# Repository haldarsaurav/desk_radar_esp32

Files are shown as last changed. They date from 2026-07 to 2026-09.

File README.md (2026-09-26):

# MUC Desk Radar

**Munich · Revision 2.1 base + unnumbered screen-look update · 26 September 2026**

Designed and built by **Saurav Haldar**.

> Copyright 2026 Saurav Haldar / @haldarsaurav. All rights reserved. Permission is required
> for reuse. See the [licence](LICENSE) and [permission guide](docs/PERMISSIONS.md).

<p align="center">
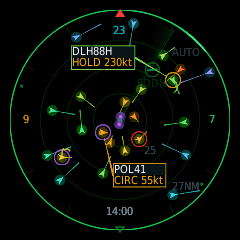
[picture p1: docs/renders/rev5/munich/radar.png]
MUC Desk Radar firmware render with example aircraft near Munich
  
</p>

<p align="center">
  <strong>A tiny, physical window into the sky above Munich.</strong>
</p>

MUC Desk Radar is a standalone Wi-Fi aircraft tracker built around an ESP32-S3 and a 240 × 240 round display. It turns live ADS-B positions, airport weather, orbital data and its own learned traffic history into a quiet desk instrument.

There is no phone app, subscription, account or home server. Once Wi-Fi is configured, the device talks directly to public data sources and draws everything locally.

**Real device photos:** reserved for Saurav's photos of the assembled radar in use. The images below are labeled firmware captures, setup-page captures or CAD renders; none is presented as a photograph of the finished device.

It answers the simple question that started the project—**“What is that plane?”**—but it also answers more interesting ones:

- Is that aircraft arriving, departing, holding, circling, surveying or going around?
- What will pass closest to home if every aircraft keeps its present course?
- Which contact is the most unusual—not merely the nearest?
- Is the sky genuinely busier than it normally is on this weekday and hour?
- Which runway direction is probably active?
- Where is the ISS in my sky, and when is its next useful pass?

> This repository is the public, presentation-only home of the project: the complete README guide, firmware renders, wiring information and enclosure concepts. It intentionally contains **no firmware source and no private configuration**.

---

## Revision history

| Revision | Date | Changes |
| --- | --- | --- |
| **Unnumbered look update** | 26 September 2026 | Original plus five selectable screen looks; portal picker, saved selection and 30 firmware render checks. |
| **2.1** | 26 September 2026 | Fixed airport sets; startup, settings, network, stale-data and portal audit fixes; expanded regression coverage; full project credit and measured running cost. |
| **2.0** | 25 September 2026 | Baseline snapshot, previously labelled product 2.3 / firmware 5.7.1. |

The owner has reset release numbering to **2.0 → 2.1**. Historical rev5.x and rev2.2/2.3
comments describe earlier development; current firmware, screen and boot labels are 2.1.

## Money to run

Measured running power: **0.6 W**. At that constant draw, leaving the radar on 24/7 uses
**0.0144 kWh/day**, **0.432 kWh per 30 days**, or **5.256 kWh per 365-day year**.

For a Freising example, [Freisinger Stadtwerke's MaxiStrom tariff](https://www.freisinger-stadtwerke.de/de/Energie-Wasser/Strom/Unsere-Tarife/) lists a gross energy price of **€0.3095/kWh** from 1 January 2026. At that rate, the radar adds about **€0.0045/day**, **€0.13 per 30 days**, or **€1.63/year** in electricity. This is the incremental energy charge on an existing connection; it excludes the tariff's standing charge. Your actual bill depends on your tariff and measured power over time.

## At a glance

| Item | Detail |
|---|---|
| Display | 1.28-inch GC9A01 round IPS, 240 × 240 pixels |
| Controller | ESP32-S3-WROOM-1 N16R8, dual core, 16 MB flash, 8 MB PSRAM |
| Local controls | One MODE button; all configuration is through a captive web page |
| Main aircraft refresh | Approximately every 8 seconds |
| Drawing rate | Approximately 40 frames per second |
| Stored contacts | Up to the nearest 96 contacts from the shared aircraft request |
| Radar AUTO ladder | 10, 15, 20, 30, 50, 75, 100, 150 or 250 km |
| Behavior memory | Up to 64 aircraft tracks × 48 position fixes |
| Traffic memory | 60 one-minute samples, an hourly baseline and a learned 7 × 24-hour weekly model |
| Special alerts | Squawk 7500, 7600 and 7700 |

---

## Real screens from the firmware

These are host-rendered examples from the firmware drawing code, not photographs or live captures. The screen set was regenerated from revision 2.1 using synthetic aircraft and weather fixtures; exact labels and units depend on settings. The descriptions below explain the current Munich configuration.

| Live radar | Munich Airport | Traffic now |
|---|---|---|
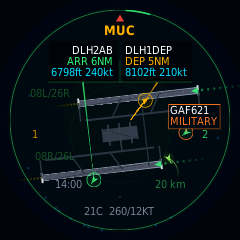
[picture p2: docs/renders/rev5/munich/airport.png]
Munich airport page
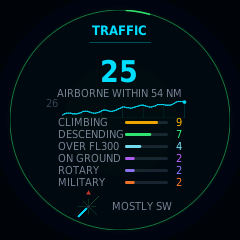
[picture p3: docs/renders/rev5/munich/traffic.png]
Munich traffic page
| Munich radar page |  |  |
| Nearest aircraft | Coolest aircraft | Space |
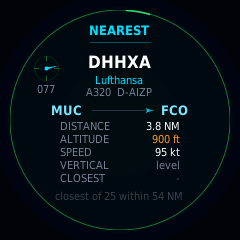
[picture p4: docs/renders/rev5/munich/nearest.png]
Nearest aircraft page
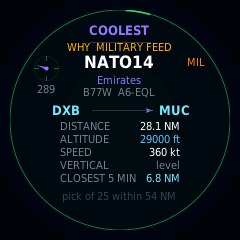
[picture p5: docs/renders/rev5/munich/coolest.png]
Coolest aircraft page
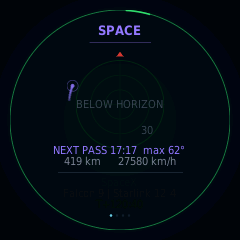
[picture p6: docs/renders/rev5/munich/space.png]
ISS and launches page
|  |  |  |
| Weather | Detected patterns | Learned trends |
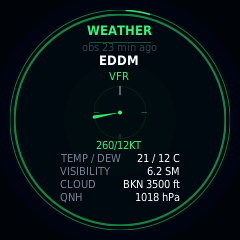
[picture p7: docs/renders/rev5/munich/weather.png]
Weather page
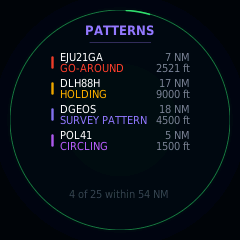
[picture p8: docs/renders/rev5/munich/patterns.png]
Flight patterns page
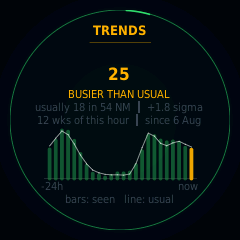
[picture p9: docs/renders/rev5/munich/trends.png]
Traffic trends page
|  |  |  |
| System health | About | Connection recovery |
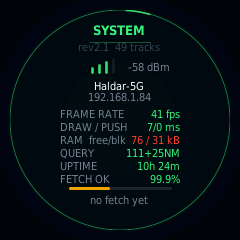
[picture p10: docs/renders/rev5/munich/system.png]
System page
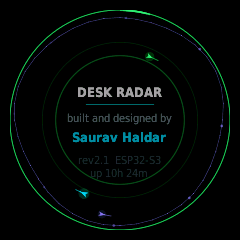
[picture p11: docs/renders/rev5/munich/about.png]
About page
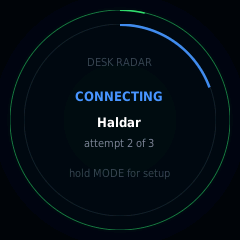
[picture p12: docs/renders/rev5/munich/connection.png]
Connection recovery page
|  |  |  |

---

## Six selectable screen looks

The current [firmware source](https://github.com/haldarsaurav/desk_radar_esp32_code) includes **Original plus five new looks**. Choose one under **Screen → Look** in the setup portal, then Save; the choice is stored and takes effect after the restart. Each look restyles the pages, connection and setup screens using the same aircraft and weather data. The images below come from the firmware's host renderer with synthetic data; they are not device photographs. Each linked strip covers the normal pages and special states.

| Look | Firmware render | More render checks |
|---|---|---|
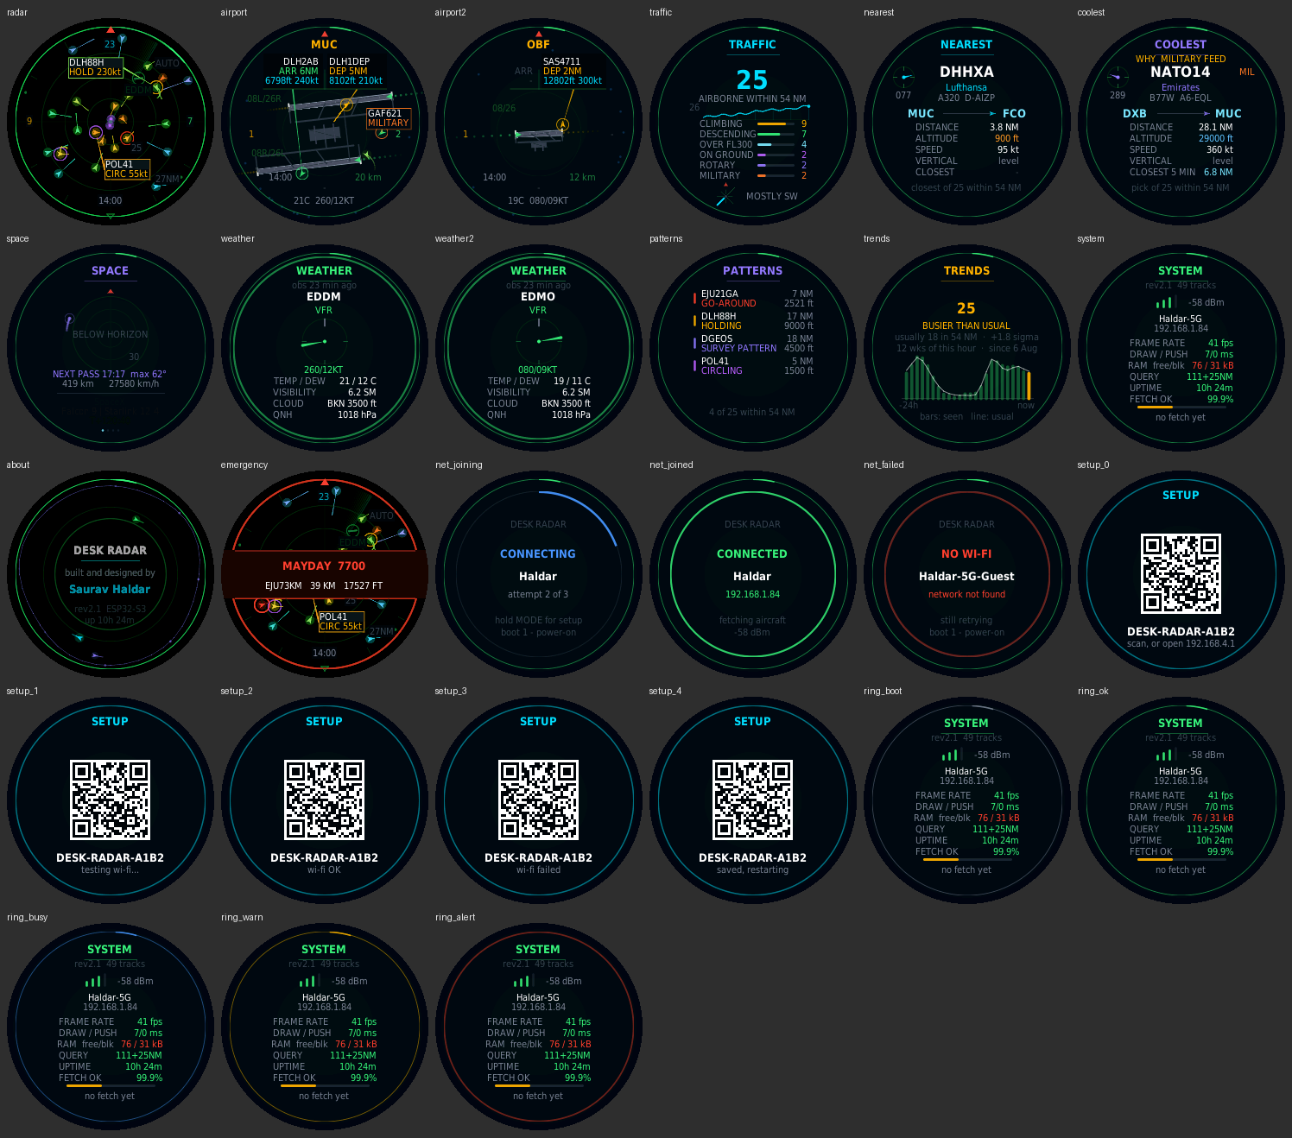
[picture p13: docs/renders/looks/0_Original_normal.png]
Original look across Desk Radar pages
| Original |  | [Empty](docs/renders/looks/0_Original_empty.png) · [Stale](docs/renders/looks/0_Original_stale.png) · [Stress](docs/renders/looks/0_Original_stress.png) · [Metric](docs/renders/looks/0_Original_metric.png) |
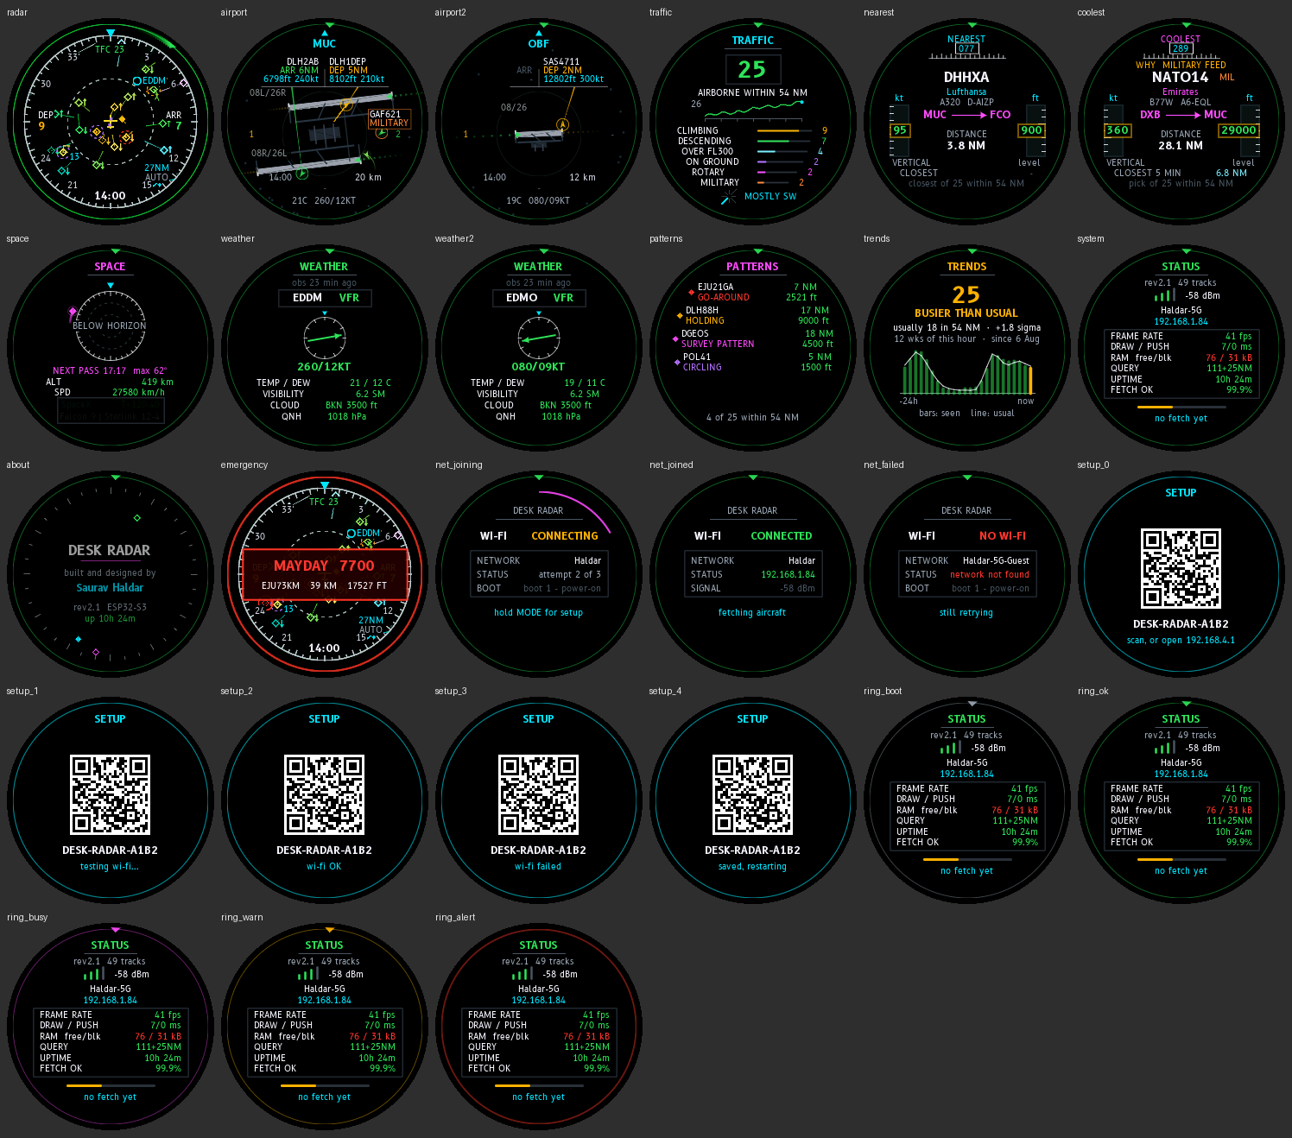
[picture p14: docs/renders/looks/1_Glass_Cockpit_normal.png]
Glass Cockpit look across Desk Radar pages
| Glass Cockpit |  | [Empty](docs/renders/looks/1_Glass_Cockpit_empty.png) · [Stale](docs/renders/looks/1_Glass_Cockpit_stale.png) · [Stress](docs/renders/looks/1_Glass_Cockpit_stress.png) · [Metric](docs/renders/looks/1_Glass_Cockpit_metric.png) |
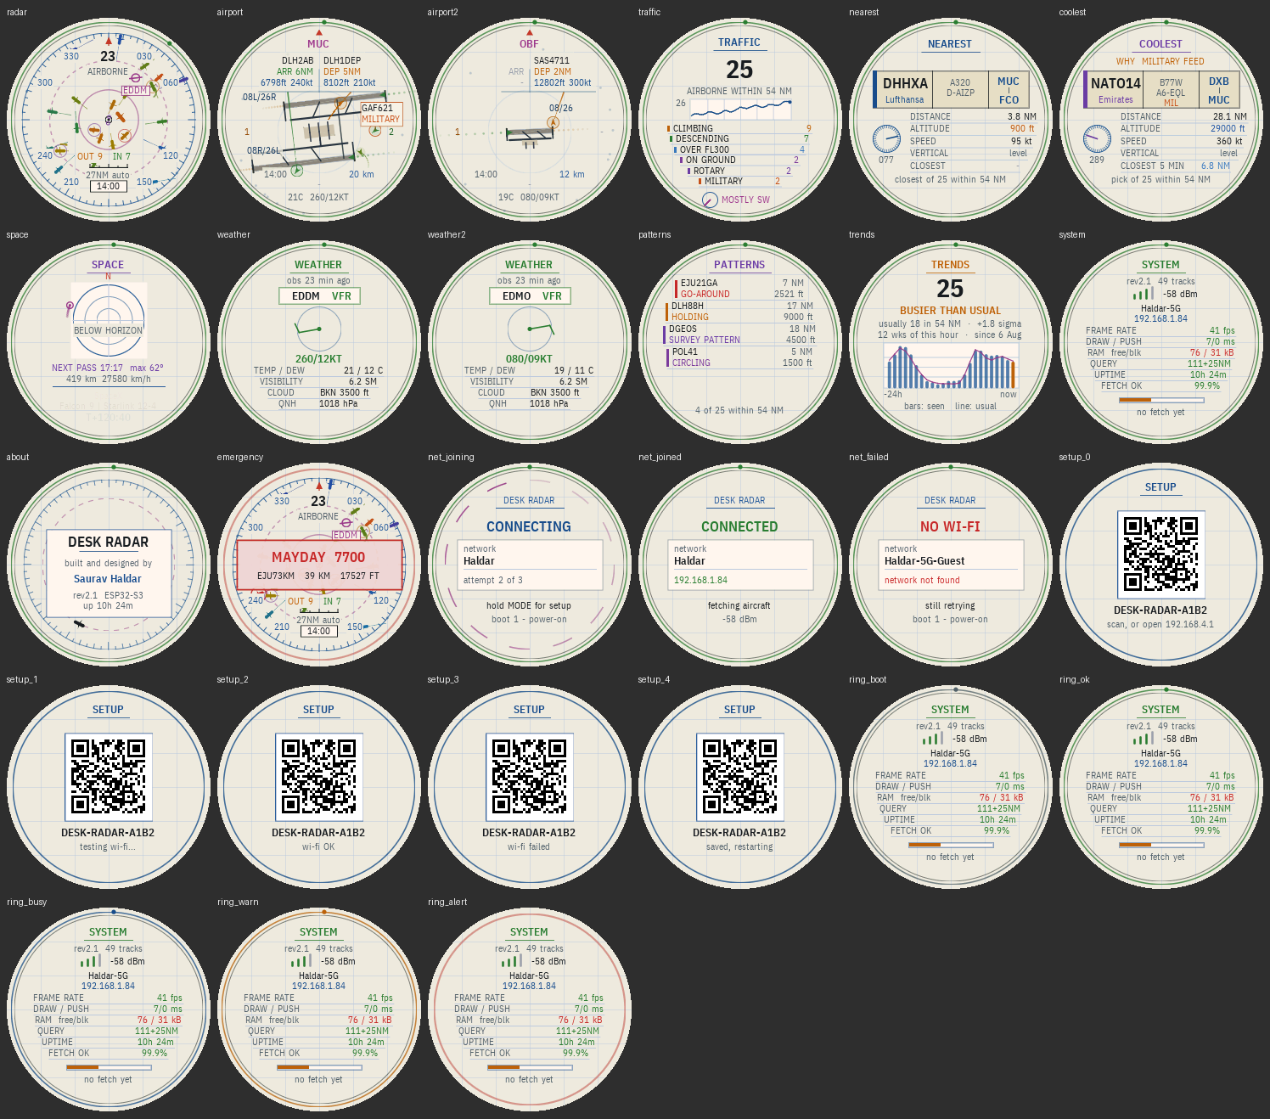
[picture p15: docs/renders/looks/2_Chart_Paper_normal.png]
Chart Paper look across Desk Radar pages
| Chart Paper |  | [Empty](docs/renders/looks/2_Chart_Paper_empty.png) · [Stale](docs/renders/looks/2_Chart_Paper_stale.png) · [Stress](docs/renders/looks/2_Chart_Paper_stress.png) · [Metric](docs/renders/looks/2_Chart_Paper_metric.png) |
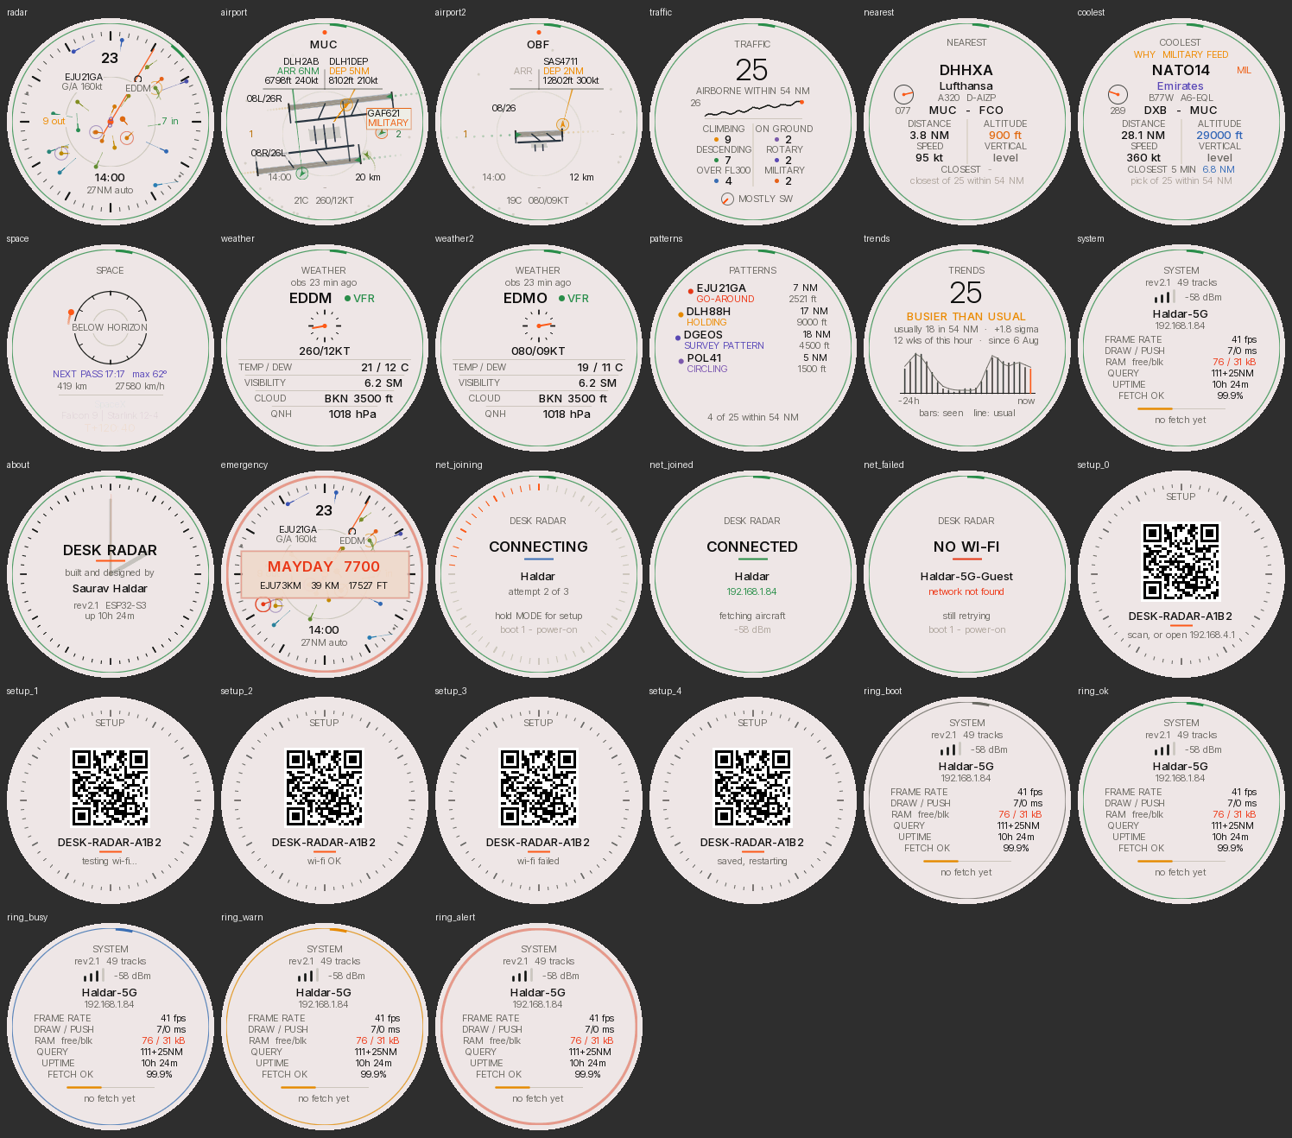
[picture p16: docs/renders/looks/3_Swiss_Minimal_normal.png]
Swiss Minimal look across Desk Radar pages
| Swiss Minimal |  | [Empty](docs/renders/looks/3_Swiss_Minimal_empty.png) · [Stale](docs/renders/looks/3_Swiss_Minimal_stale.png) · [Stress](docs/renders/looks/3_Swiss_Minimal_stress.png) · [Metric](docs/renders/looks/3_Swiss_Minimal_metric.png) |
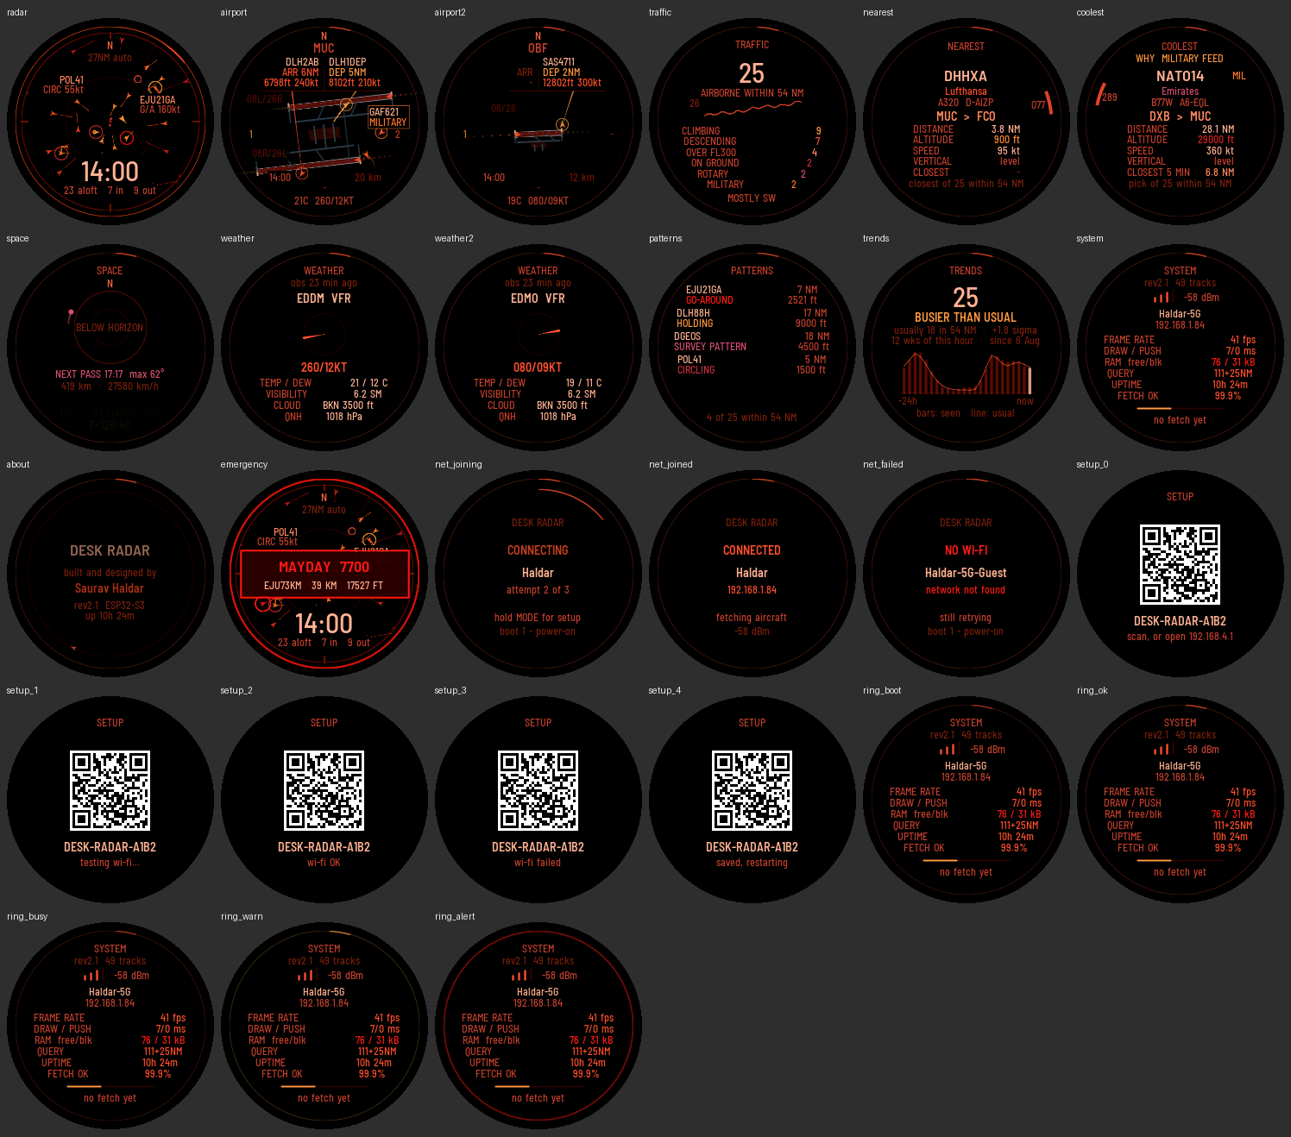
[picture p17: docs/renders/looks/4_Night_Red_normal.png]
Night Red look across Desk Radar pages
| Night Red |  | [Empty](docs/renders/looks/4_Night_Red_empty.png) · [Stale](docs/renders/looks/4_Night_Red_stale.png) · [Stress](docs/renders/looks/4_Night_Red_stress.png) · [Metric](docs/renders/looks/4_Night_Red_metric.png) |
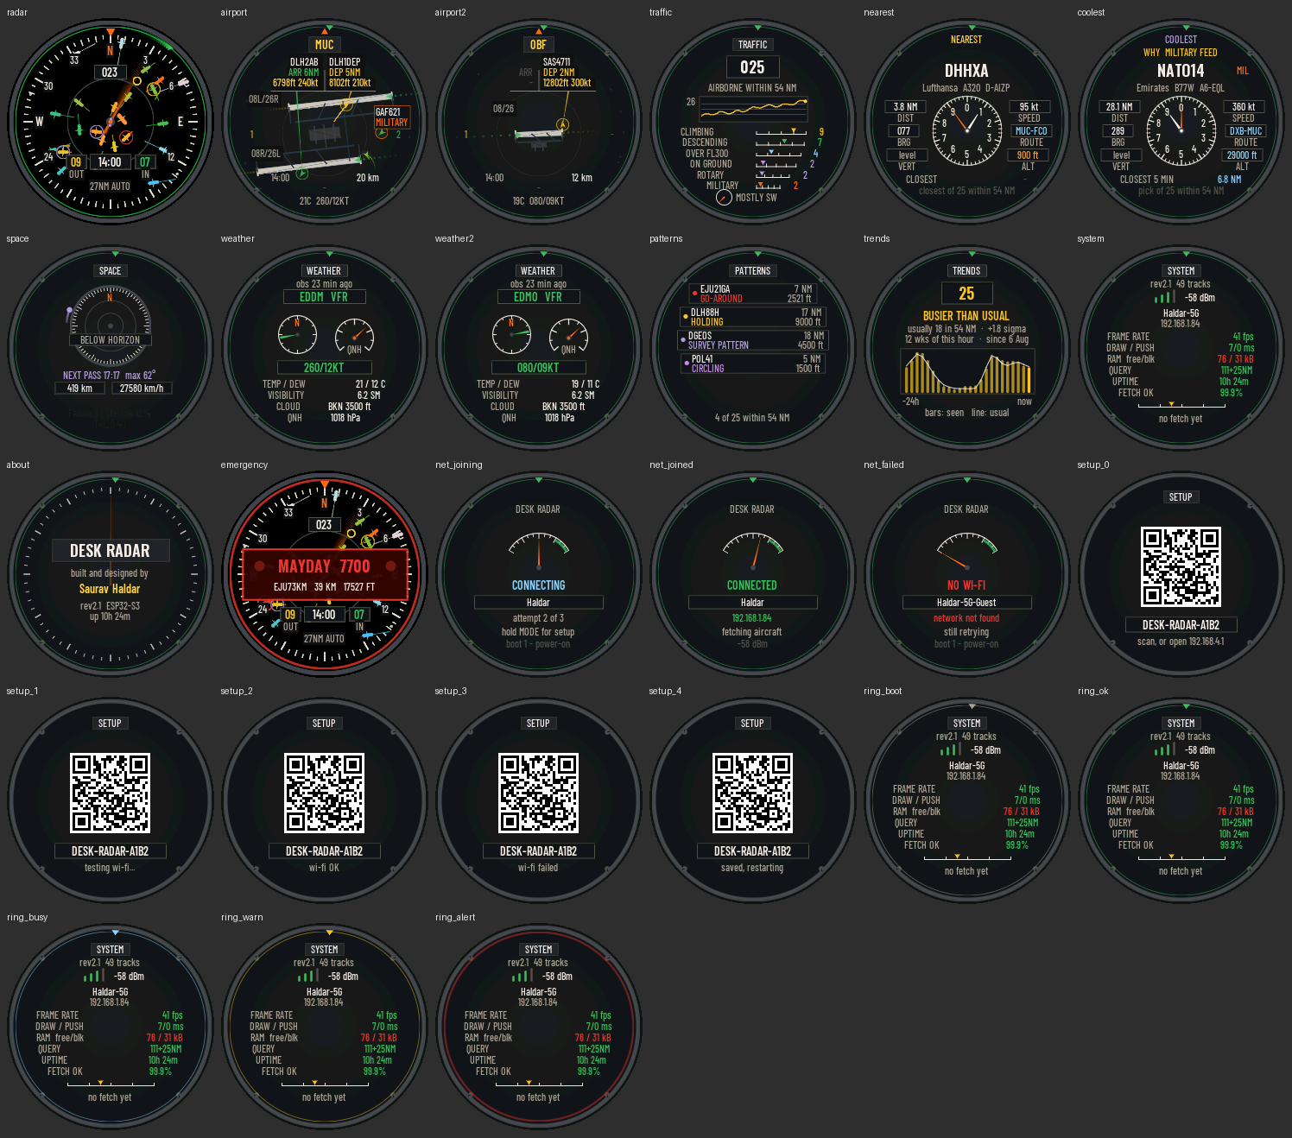
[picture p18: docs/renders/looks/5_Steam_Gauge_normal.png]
Steam Gauge look across Desk Radar pages
| Steam Gauge |  | [Empty](docs/renders/looks/5_Steam_Gauge_empty.png) · [Stale](docs/renders/looks/5_Steam_Gauge_stale.png) · [Stress](docs/renders/looks/5_Steam_Gauge_stress.png) · [Metric](docs/renders/looks/5_Steam_Gauge_metric.png) |

The earlier sheet below shows eight **design concepts** alongside Original. Amber Terminal, Neon Night and Departure Board remain concepts; they are not selectable firmware looks.

<details>
<summary>View the earlier nine-look concept sheet</summary>

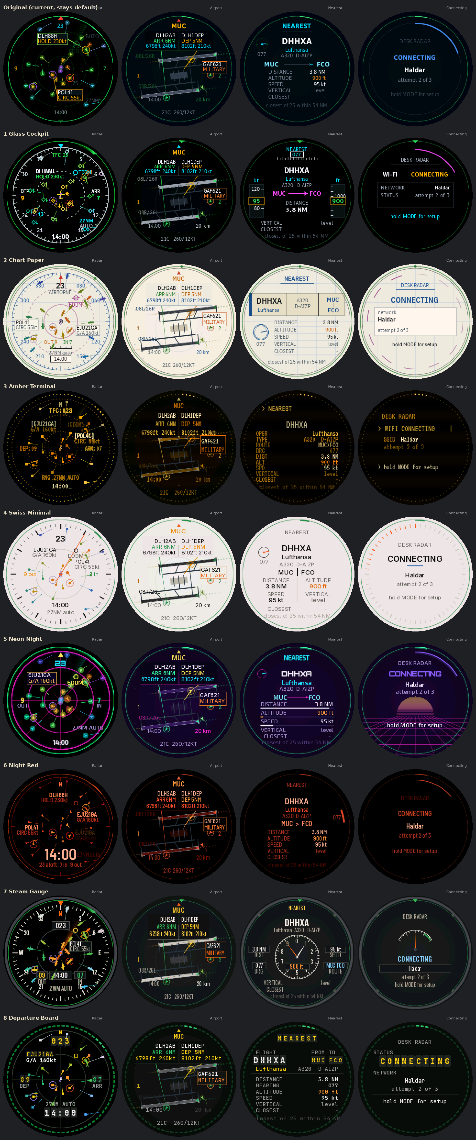
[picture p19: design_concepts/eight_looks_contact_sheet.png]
Contact sheet showing the original Desk Radar look and eight visual concepts across four screen states


</details>

Earlier product shape and screen studies are archived below. They are concept images rather than photos of a built enclosure or additional firmware pages.

<details>
<summary>View enclosure and screen concept gallery</summary>

| Direct stack | Tilted lid | Bridge pod |
|---|---|---|
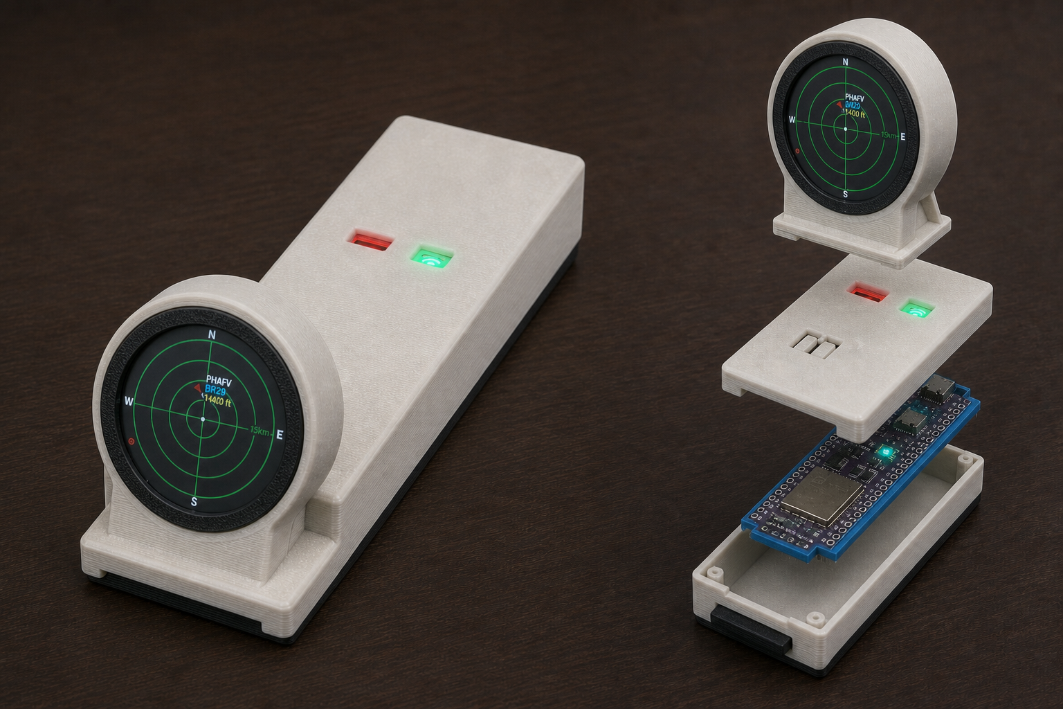
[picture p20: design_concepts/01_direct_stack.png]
Direct stack enclosure concept
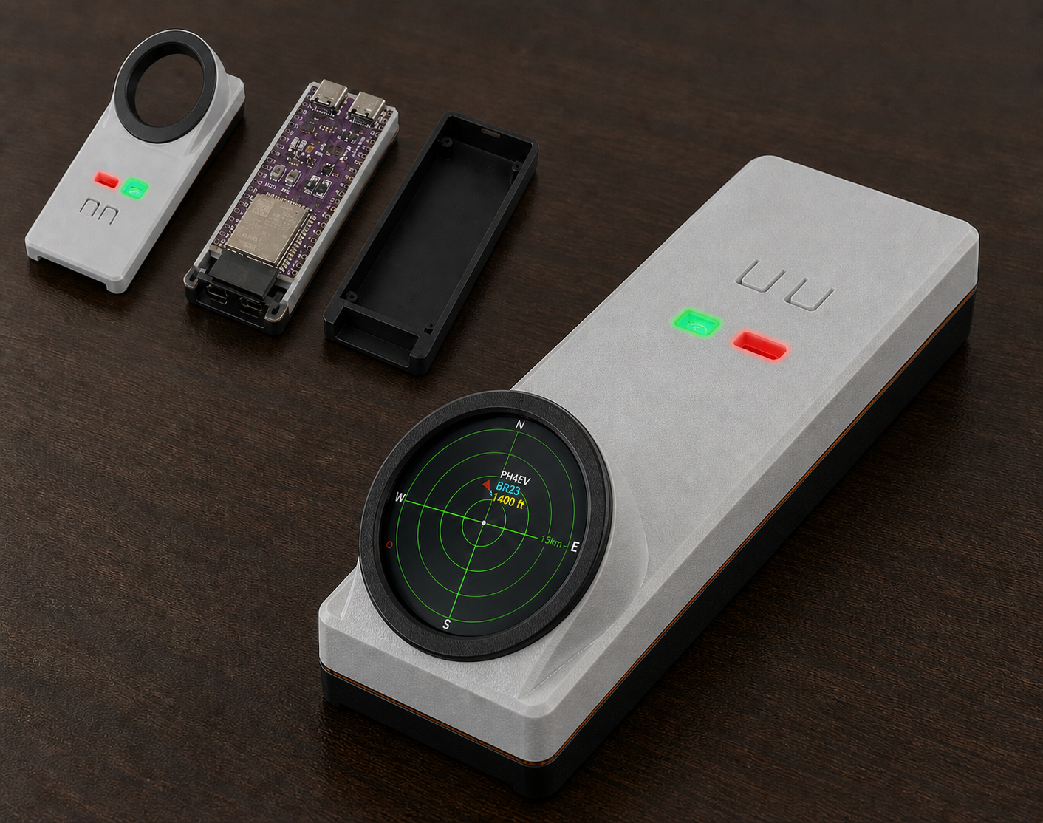
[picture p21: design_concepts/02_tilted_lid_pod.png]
Tilted lid enclosure concept
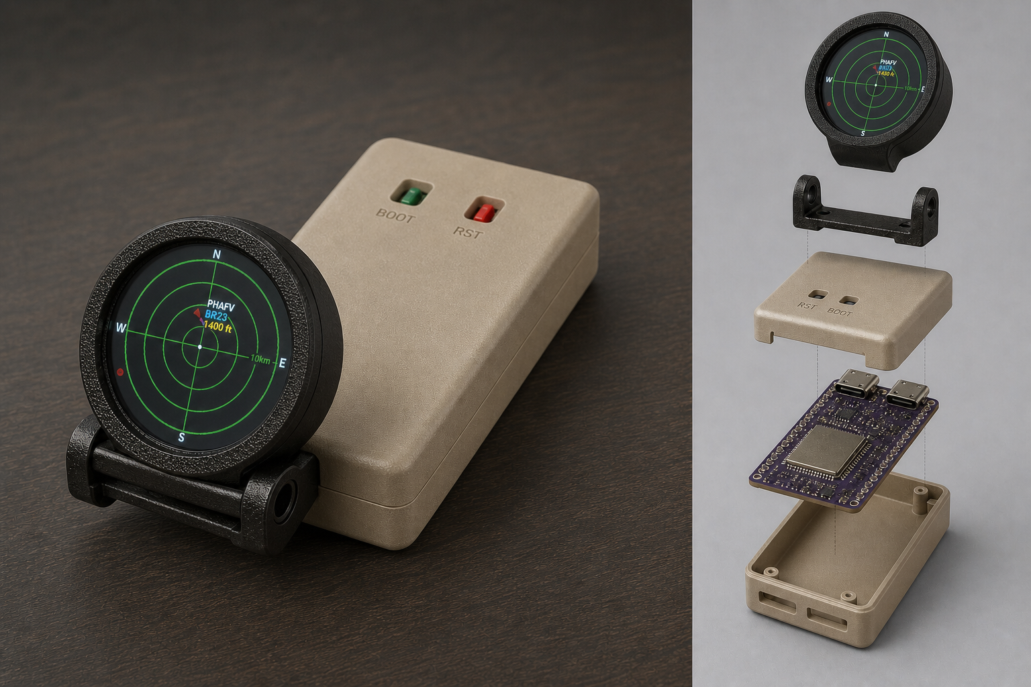
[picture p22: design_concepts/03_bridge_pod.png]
Bridge pod enclosure concept
|  |  |  |
| Monolithic end cap | Twin fin | Selected stack study |
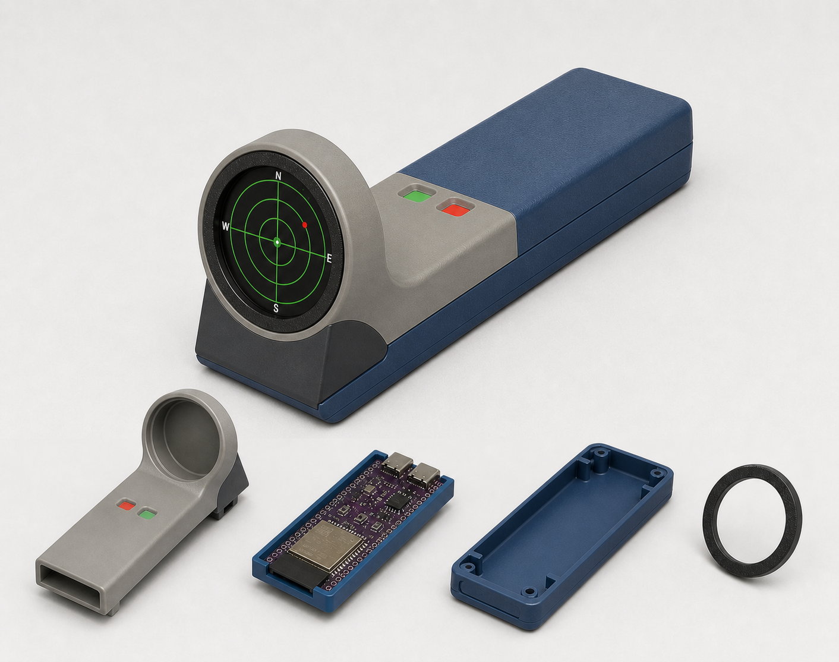
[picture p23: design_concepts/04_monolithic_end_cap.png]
Monolithic end cap enclosure concept
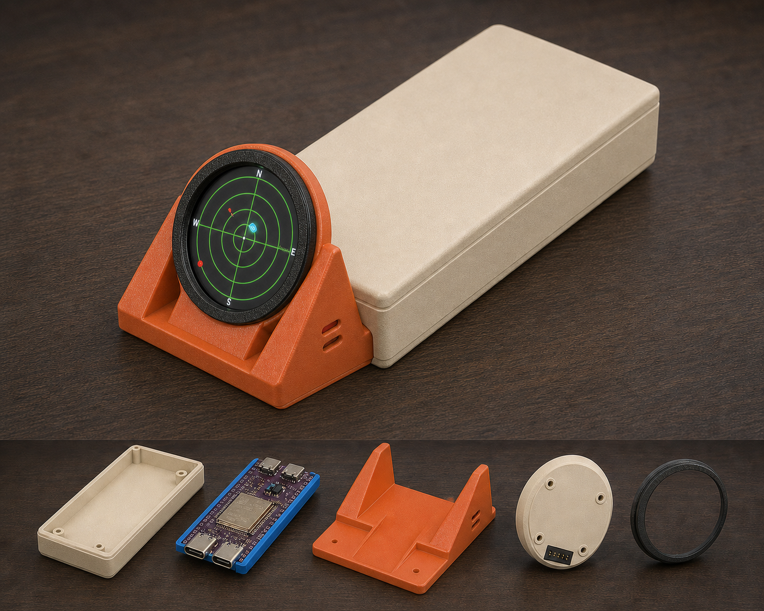
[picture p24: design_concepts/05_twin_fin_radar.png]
Twin fin enclosure concept
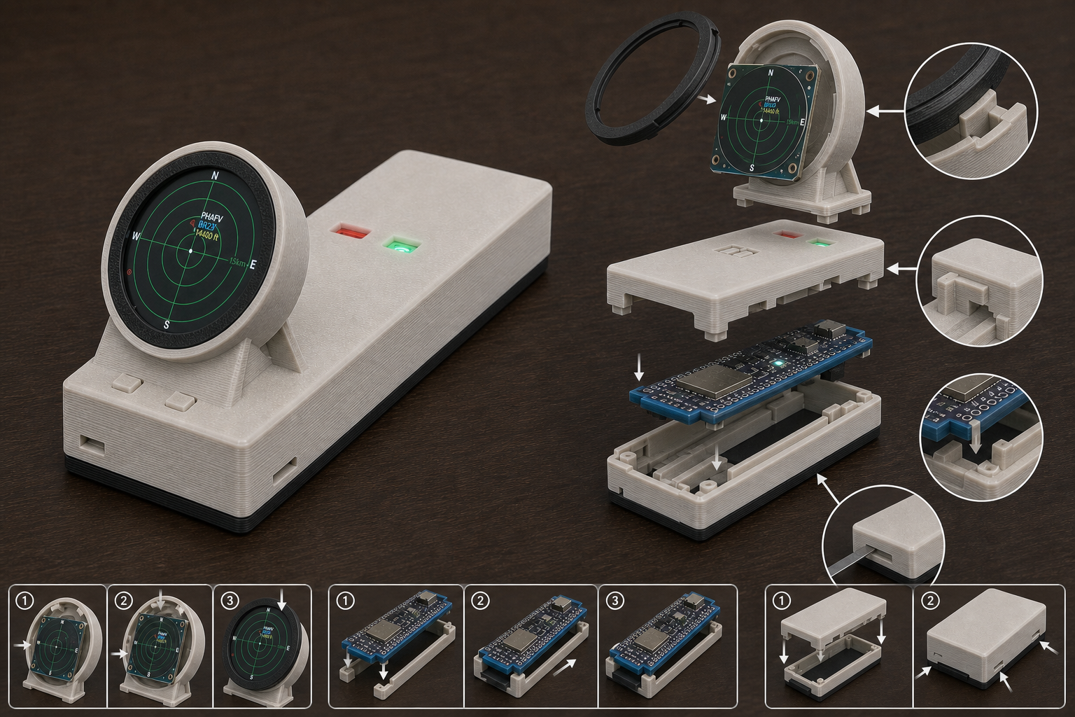
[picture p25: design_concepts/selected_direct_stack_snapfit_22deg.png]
Selected direct stack study
|  |  |  |
| Black and green product study | White upright product study | Radar screen study |
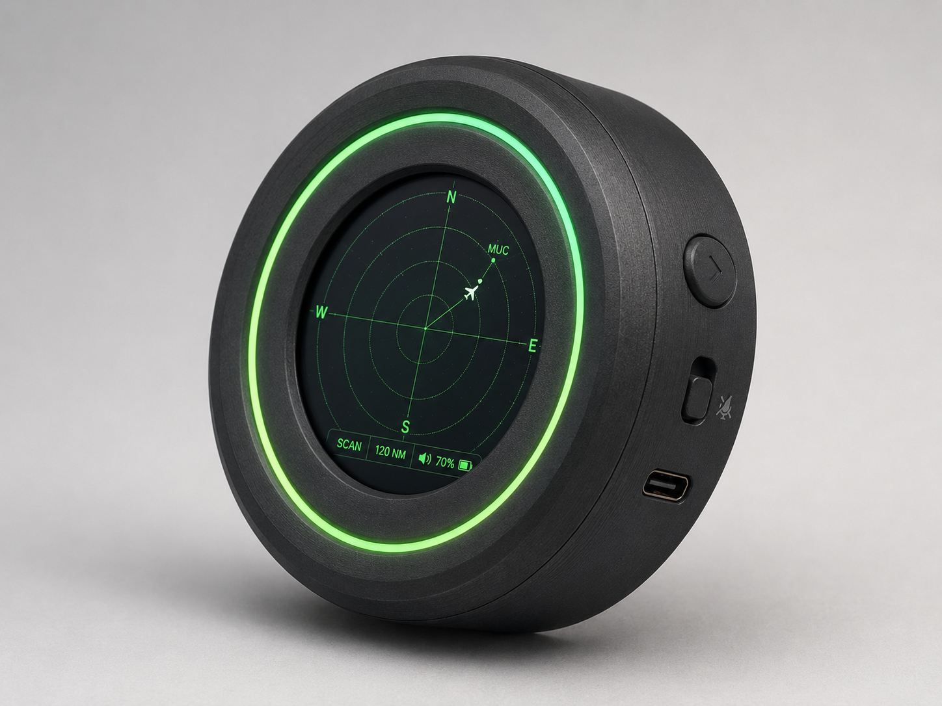
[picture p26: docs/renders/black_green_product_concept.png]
Black and green product concept
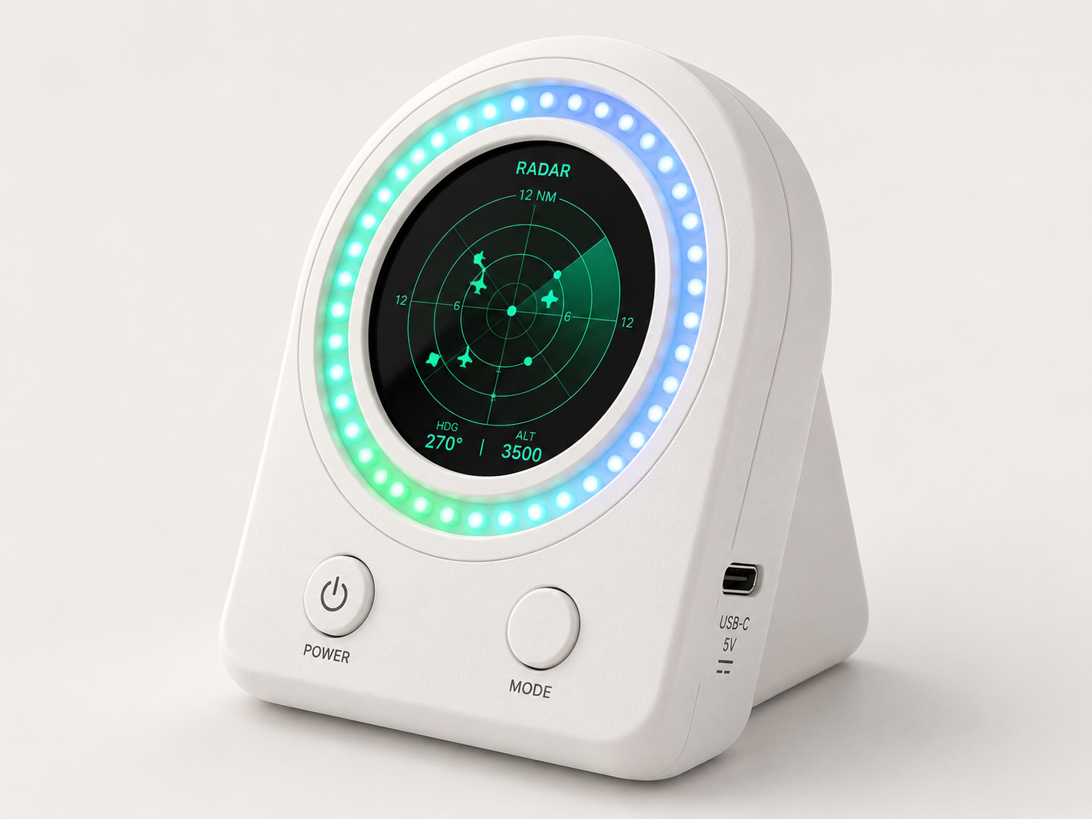
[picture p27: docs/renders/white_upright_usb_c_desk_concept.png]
White upright product concept
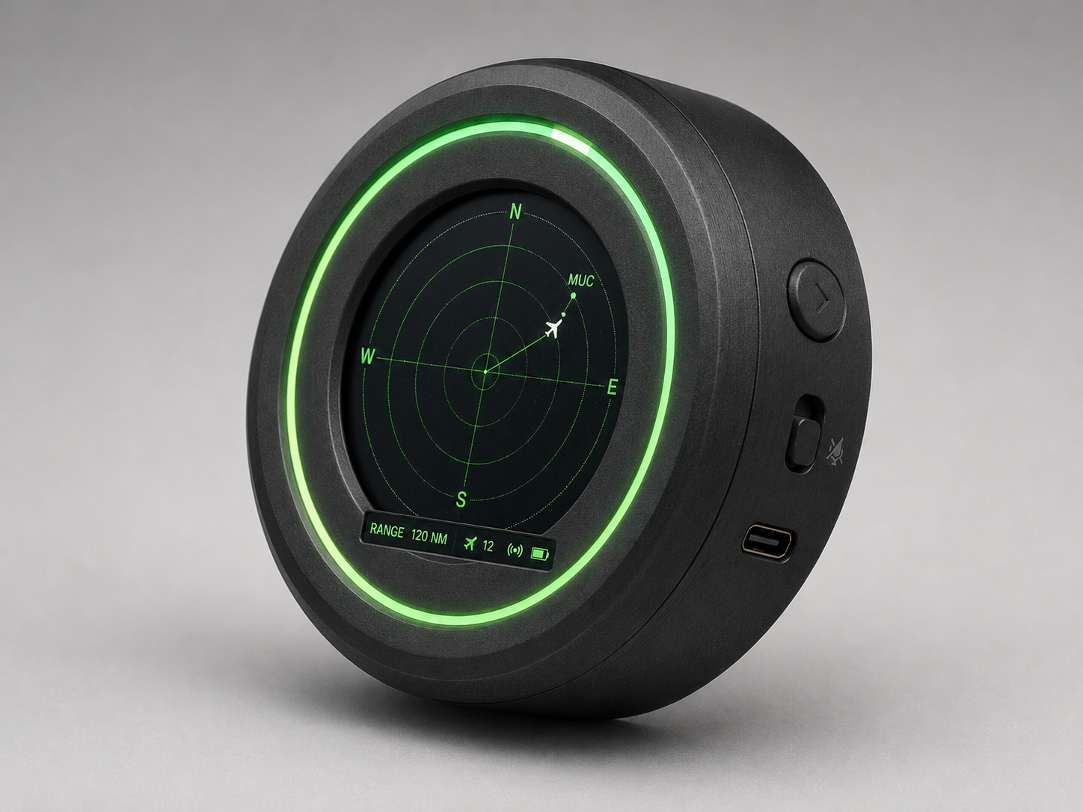
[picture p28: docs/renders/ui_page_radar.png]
Early radar screen concept
|  |  |  |
| Airport screen study | Closest aircraft study | Traffic statistics study |
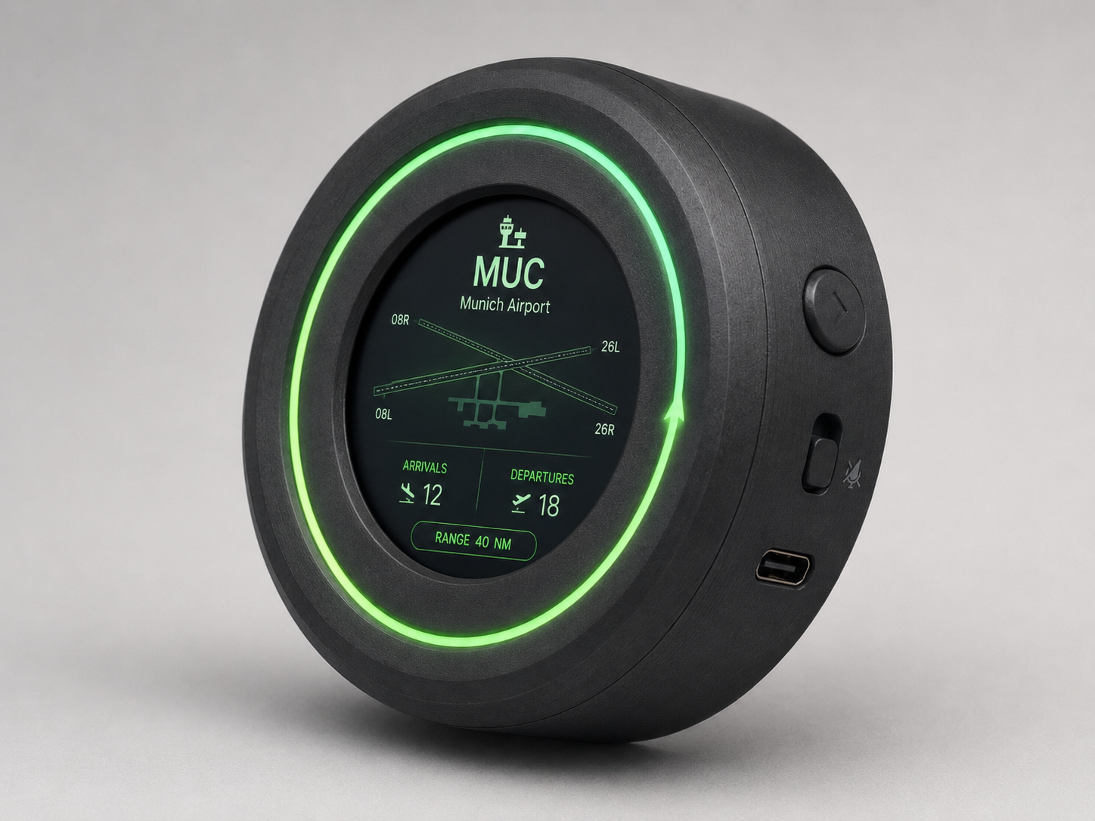
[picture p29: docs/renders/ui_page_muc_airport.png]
Early Munich Airport screen concept
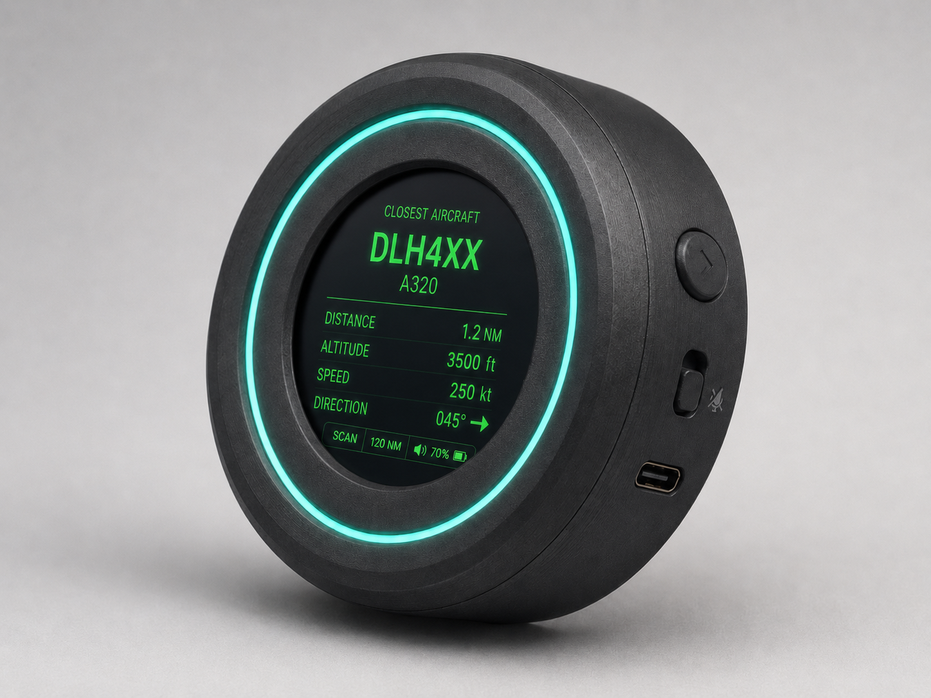
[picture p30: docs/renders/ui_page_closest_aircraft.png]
Early closest-aircraft screen concept
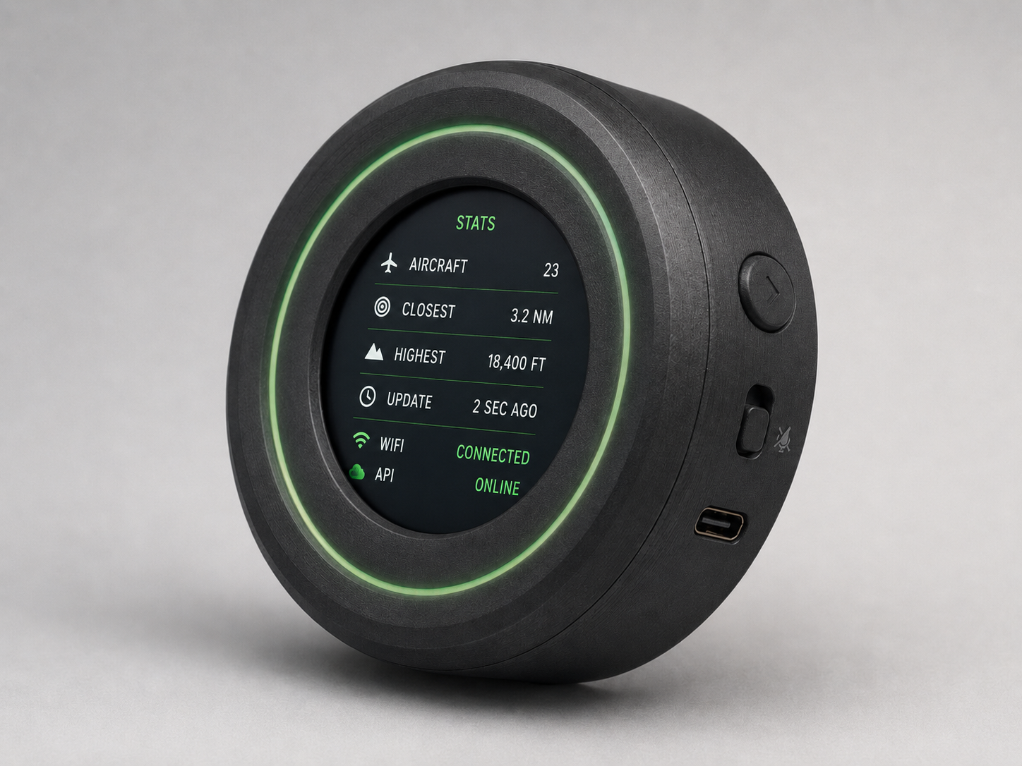
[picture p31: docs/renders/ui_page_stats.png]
Early traffic statistics screen concept
|  |  |  |
| System screen study | Round case reference | ESP32 case reference |
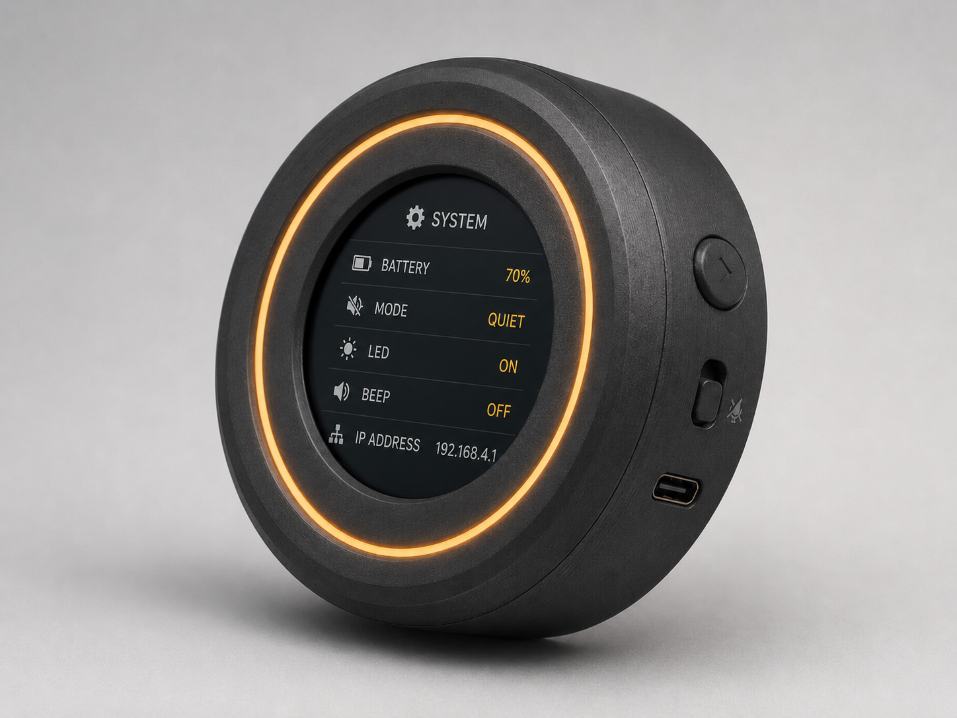
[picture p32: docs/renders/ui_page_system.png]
Early system screen concept
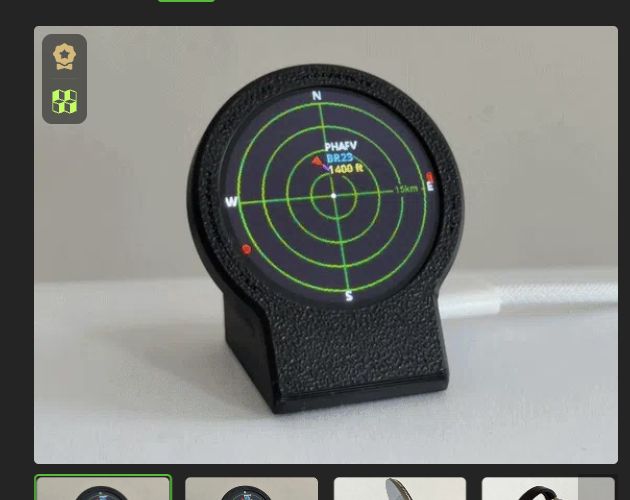
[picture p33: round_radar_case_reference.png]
Round radar case reference image
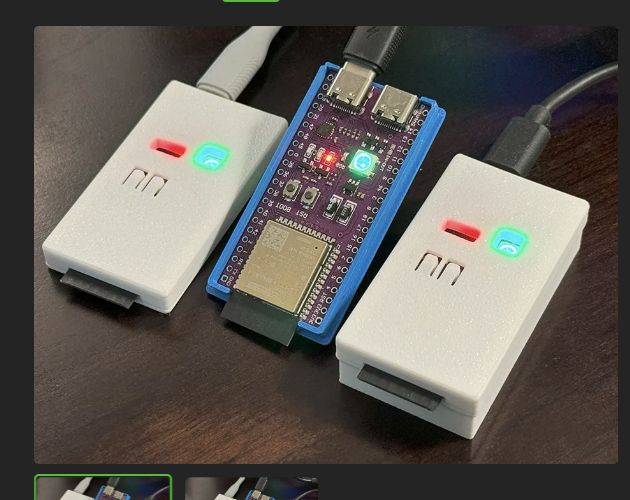
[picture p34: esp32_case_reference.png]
ESP32 board case reference image
|  |  |  |

</details>

---

## The idea: a tiny spotting assistant

Most flight trackers are maps on a phone or browser. This is deliberately a physical object: closer to a miniature cockpit instrument than another app.

The circular screen is small, so the design favors information that works at a glance:

- arrowheads show aircraft direction;
- color shows altitude;
- motion leaders hint at speed;
- real trails show what a contact has actually done;
- short labels mark detected behavior;
- airport geometry is drawn at the correct orientation and scale;
- the most important values sit outside the moving radar layer, where sweep graphics cannot cover them.

The radar does not treat every aircraft equally. A routine airliner is useful, but a helicopter orbiting overhead, a heavy aircraft, a military flight, a fresh contact, a go-around or an emergency should win attention immediately.

---

## How a position becomes a symbol

For nearby aircraft, latitude and longitude are converted into a local east/north plane centered on home:

- north distance ≈ latitude difference × 111.195 km;
- east distance ≈ longitude difference × 111.195 km × cos(home latitude);
- range = √(east² + north²);
- true bearing = atan2(east, north), normalized to 0–359°.

The local approximation is fast and accurate at desk-radar ranges. Long-distance calculations, including ISS ground distance, use a great-circle/Haversine model with an Earth radius of 6,371 km.

Each valid contact is checked for plausible coordinates, altitude and speed. Between network updates, the last good fix is carried forward using track and groundspeed, so an aircraft moves smoothly instead of jumping once every eight seconds.

### Altitude color

Color is continuous: values are interpolated between these stops.

| Altitude | Color | Meaning on the display |
|---:|---|---|
| 0 ft | Orange | Ground or very low |
| 4,000 ft | Yellow | Low traffic |
| 12,000 ft | Green | Climbing/descending traffic |
| 24,000 ft | Cyan | High traffic |
| 34,000 ft | Blue | Typical cruise |
| 45,000 ft | Violet | Very high |

The palette makes height readable without spending precious pixels on a label beside every target.

### Velocity leaders

A short line in front of each aircraft communicates speed. The projection time grows with radar range:

**leader time = clamp(range in km × 1.2, 10 seconds, 90 seconds)**

Projected distance is groundspeed converted from knots to km/h, multiplied by the leader time. The final line is capped at 30% of the scope radius, so fast aircraft remain legible without drawing across the whole screen.

### Trails that show actual movement

The sweep has phosphor-style persistence, but aircraft trails are not decorative screen burn. They come from retained position history:

- up to 48 fixes are retained for a tracked aircraft;
- the radar uses the newest 14 points;
- the visible trail is capped at 22 pixels;
- very short sub-pixel segments are skipped;
- older segments fade smoothly.

The cap is in screen pixels rather than kilometers, so trails remain useful at every zoom level. Their time span depends on the live polling cadence; at the normal aircraft refresh rate they represent several minutes of recent movement.

This matters because a 450-knot aircraft on a 50 km scope moves only about 0.17 display pixels during a short phosphor decay. A frame-fade alone can show a rotating sweep, but it cannot show an honest aircraft path.

---

## Four radii, two centers

The device deliberately separates **what is drawn**, **what counts as local**, **what an airport page needs**, and **what must be downloaded**.

| Quantity | Center | Purpose | Changes what? |
|---|---|---|---|
| Radar range | Home | Size of the visible radar scope | Drawing only; AUTO may change it |
| Activity radius | Home | Definition of “your sky” | Traffic, Coolest, Patterns and Trends |
| Airport map range | Reference airport | Area visible around the runway diagram | Airport page only |
| Fetch radius | Shifted request center | One shared request large enough to contain both home and airport circles | Network coverage |

This presentation covers Munich, with Munich Airport (MUC / EDDM) as the reference field. The home position is set separately in the setup page.

The shared aircraft request is shifted and widened when necessary so both circles fit inside it. That avoids two simultaneous live-aircraft requests while still letting a distant home and airport have independent views.

This separation is also why AUTO zoom never silently changes the statistical meaning of “local traffic.” Trends remain comparable even while the picture zooms in and out.

---

## AUTO radar range

AUTO tries to keep the radar useful without nervous zooming.

### The range ladder

It chooses only from:

**10 → 15 → 20 → 30 → 50 → 75 → 100 → 150 → 250 km**

The user may set lower and upper bounds. The default AUTO window is 20–100 km.

### What it measures

Once per minute, AUTO counts airborne contacts inside every allowed rung. It chooses the smallest range containing at least six airborne aircraft. If no allowed rung reaches six, the widest allowed range becomes the target.

AUTO evaluates the complete airborne picture, even when the display is temporarily filtered to military-only traffic. A visual filter therefore cannot make the physical zoom hunt.

### Why it changes slowly

The first valid evaluation can settle the initial range. Later decisions use the median of the preceding hour’s valid minute samples and move only one rung toward that target. A flickering count cannot demand a rapid zoom change. Stale data and emergency alerts suspend the decision.

The result feels like an instrument adapting to the day, not a camera constantly zooming. The screen prints **AUTO** whenever this mode is active.

AUTO changes only the visible radar range. It does not change the fixed activity radius, the airport map or the learned traffic baseline.

---

## Every page, in detail

### RADAR — the live sky

<p align="center">Radar page with range rings, trails and behavior labels</p>

The main page is centered on home. Range rings provide scale, aircraft arrows show true track, and altitude color, velocity leaders and trails reveal three different dimensions without clutter.

The default sweep turns at about 6 rpm—one revolution every 10 seconds. It is rendered beneath the information layer, so the glow cannot erase a label or page status. Detected behaviors appear as short labels such as HOLD, CIRC, SURV or G/A.

### AIRPORT — runway geometry and operations

<p align="center">Munich Airport view</p>

This page is centered on the reference airport, not on home. Runways are drawn using their real headings, lengths and relative positions. Aircraft are classified as arrivals, departures or ground traffic.

The likely active landing end is chosen from METAR wind: the runway direction pointing most nearly into the wind wins. If usable wind data is missing, the device can infer a likely direction from descending aircraft near the field and marks that answer in amber to show that it is inferred rather than reported.

Ground symbols are intentionally different:

- amber chevron: moving on a runway;
- violet stub: taxiing;
- dim violet dot: parked or nearly stationary.

### TRAFFIC — what the sky is doing now

<p align="center">Traffic page showing counts, direction rose and one-hour history</p>

TRAFFIC summarizes the fixed activity circle:

- airborne now;
- climbing and descending;
- above 30,000 ft;
- on the ground;
- helicopters;
- military aircraft.

An eight-sector direction rose shows where traffic is distributed around home. The one-hour sparkline is built from 60 one-minute buckets. Multiple live samples during each minute are accumulated and committed as a rounded mean, so one noisy fetch does not become the entire minute.

The current ten-minute mean is compared with the preceding ten-minute mean to color the short-term trend.

### NEAREST — the closest contact and its future miss distance

<p align="center">Nearest aircraft detail page</p>

NEAREST chooses the retained airborne contact with the smallest current distance from home, then adds enrichment such as type, registration, operator and route when available.

It also calculates closest point of approach (CPA). In a local east/north plane:

- position vector p = (east, north);
- velocity vector v comes from track and groundspeed;
- time to CPA = −(p · v) / (v · v);
- CPA distance = |p + v × time|.

If speed is 1 knot or less, or the mathematical CPA lies in the past, there is no future CPA to show. The detail page displays it only when the predicted closest point is less than 30 minutes away.

CPA assumes constant course and constant groundspeed. It is a useful short-range projection, not an air-traffic-control prediction.

<details>
<summary><strong>Exact selection boundary</strong></summary>

NEAREST selects the closest airborne contact retained from the shared fetch. Its detail page shows NO CONTACT when that aircraft is outside the activity radius; changing the drawn radar range does not hide an aircraft that is still inside that fixed activity area.

</details>

### COOLEST — interesting beats merely close

<p align="center">Coolest aircraft detail page</p>

COOLEST searches the fixed activity circle and gives every airborne contact an interest score:

**score = 2 × behavior interest + type bonuses + rarity bonuses + altitude / 20,000**

| Signal | Score added |
|---|---:|
| Emergency descent | 200 |
| Go-around | 190 |
| Holding pattern | 140 |
| Survey pattern | 130 |
| Circling | 120 |
| Military | 100 |
| Rotorcraft | 70 |
| Never seen since boot | 45 |
| Seen fewer than three times | 15 |
| Heavy aircraft category | 20 |
| Fast climb | 50 |
| Approach | 24 |
| Departure | 20 |
| Altitude | Small tie-break: about 2 points at 40,000 ft |

A brand-new contact receives both the “never seen” and “rare” bonuses on its first evaluation, for 60 points total.

Rarity is deliberately lightweight: a 512-slot in-memory table indexed from the aircraft address. It resets on reboot. If two addresses collide in one slot, the new one is treated as familiar rather than inventing a false rarity event. That can miss an occasional novel aircraft, but it avoids falsely announcing a routine contact as special.

### PATTERNS — detecting what an aircraft is doing

<p align="center">Patterns page showing go-around, holding, survey and circling detections</p>

The detector does not decide from a single arrow. It builds track statistics from recent fixes:

- signed and absolute accumulated turn;
- actual path length and straight-line displacement;
- bounding-box span;
- minimum and maximum altitude;
- distance trend from home;
- heading reversals greater than 140°;
- vertical rate, speed, sample count and elapsed time.

The principal detectors use these conditions:

| Behavior | Main evidence required |
|---|---|
| Holding | At least 8 samples and 60 s; ≥120 kt; at least 300° net turn; span ≤22 km; altitude spread ≤2,500 ft; displacement ≤35% of flown path; fewer than 2 reversals |
| Circling | At least 6 samples and 45 s; at least 300° turn; span ≤6 km; speed ≤160 kt; fewer than 2 reversals |
| Survey | At least 12 samples and 120 s; at least 3 heading reversals; path ≥8 km; displacement ≤30% of path; altitude spread ≤2,000 ft |
| Go-around | At least 12 samples; a genuine low point followed by ≥700 ft climb after ≥700 ft descent; current climb ≥300 ft/min; low point near airport ≤4,000 ft, elsewhere ≤2,500 ft |
| Emergency descent | Current vertical rate ≤−3,500 ft/min and more than 3,000 ft lost in the history window |

If none of those shapes is present, simpler state labels can describe a fast climb, approach, departure, high-level overflight or ordinary level flight.

This is behavior inference from public position data. It can identify a convincing shape; it cannot know the crew’s clearance or intent.

### TRENDS — learning what “normal” means here

<p align="center">Trends page comparing current traffic with learned normal</p>

The radar learns both a **24-hour daily model** and a **7 × 24-hour weekly model**. The daily model gives an initial comparison on day three when enough valid samples exist; the weekday/hour model takes over as it matures. Missing or stale feed periods do not count as quiet skies.

Each bucket keeps a running mean, variance and sample count. TRENDS explicitly waits for fresh data when the feed is stale, and missing minutes break the sparkline instead of connecting unrelated observations.

The comparison is a z-score:

**z = (current airborne count − learned mean) / standard deviation**

To stop a nearly constant quiet hour from producing absurd sensitivity, the standard deviation has a floor of:

**1 + 15% of the learned mean**

| z-score | Display verdict |
|---:|---|
| Above +2 | Much busier |
| +1 to +2 | Busier |
| −1 to +1 | Normal |
| −2 to −1 | Quieter |
| Below −2 | Much quieter |

Each bucket retains up to 12 effective observations; after that, old influence decays gently. This makes the model resemble a rolling seasonal memory rather than an eternal average. The learned model is saved in non-volatile storage and survives reboot.

Because Trends always measures the fixed activity radius, an AUTO zoom change never corrupts the comparison.

### SPACE — ISS position, pass estimate and launches

<p align="center">Space page with ISS sky position and launch countdown</p>

The ISS position is refreshed about once per minute. Ground distance uses Haversine geometry; azimuth uses the initial great-circle bearing and handles date-line wrapping.

The dome is a sky view:

- outer ring = horizon;
- center = zenith;
- radial position = dome radius × (1 − elevation / 90°).

The station is considered visibly favorable only when all three are true:

- elevation is above 10°;
- the ISS data says the station is sunlit;
- the observer’s location is in darkness.

The trail and forward leader use the live orbital speed and ground distance to estimate angular motion. The visual arc is clamped so it remains useful both near and below the horizon.

#### How the next-pass estimate works

After two valid position fixes establish a heading, the device:

1. assumes a circular orbit at the reported altitude;
2. derives an orbital period from the live speed and orbital circumference;
3. propagates the great-circle position in one-minute steps;
4. subtracts Earth’s sidereal rotation, 360° per 1,436.07 minutes;
5. searches the next 1,440 minutes for elevation above 10°;
6. records pass start and estimated maximum elevation.

The derived orbital period must be between 60 and 200 minutes. The model intentionally ignores orbital precession, so the result is an approximate spotting aid rather than an ephemeris.

The lower panel rotates through the next four launches from The Space Devs, with a live T− countdown before launch and T+ age after the scheduled time.

### WEATHER — METAR translated for a glance

<p align="center">Decoded airport weather page</p>

The airport METAR is refreshed about every 10 minutes and shown with the age of the actual observation. The page presents:

- VFR, MVFR, IFR or LIFR flight category;
- wind direction and speed on a wind rose;
- visibility and cloud information;
- temperature and dew point;
- pressure;
- a near-saturation warning when temperature and dew point are within roughly 2°C.

The same wind direction feeds the airport page’s probable active-runway calculation.

### SYSTEM — proving the instrument is healthy

<p align="center">System diagnostics page</p>

SYSTEM exposes the details that make a small network appliance trustworthy: Wi-Fi state, active aircraft feed, fetch success, frame time, memory, uptime and data freshness.

The aircraft parser validates incoming values and keeps the last good picture if a fetch fails. The service can fall back from adsb.lol to adsb.fi, apply longer backoff after server refusal or rate limiting, and later probe the preferred feed again.

### ABOUT — the quiet signature page

<p align="center">Animated About page</p>

ABOUT is deliberately playful: orbiting chevrons, a slow radar ping and the build credit. Like every normal page, it can be disabled in settings.

---

## Special states

| Recovering a connection | Emergency squawk |
|---|---|
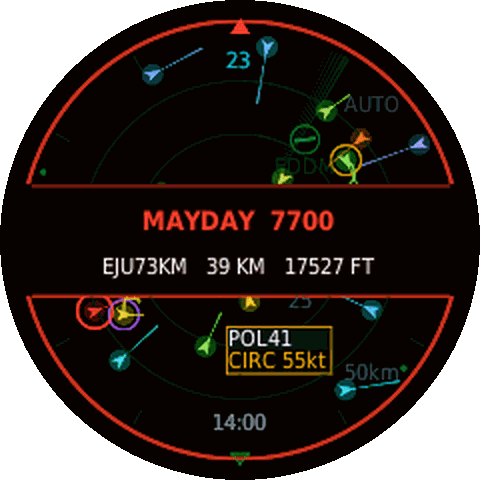
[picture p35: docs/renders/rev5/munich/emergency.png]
Emergency squawk screen
| Connection recovery screen |  |

The connection screen makes first setup and network recovery understandable without a serial console.

An airborne contact squawking one of the international emergency codes takes over the full display:

| Squawk | Meaning |
|---:|---|
| 7500 | Unlawful interference / hijack |
| 7600 | Radio communication failure |
| 7700 | General emergency |

During an emergency alert, ordinary page cycling and AUTO range changes are suppressed so the warning remains stable.

---

## Complete visual language

The display uses the same visual grammar on every page. Once these marks are familiar, most screens can be read without searching for a legend.

### General colors

| Color | Meaning |
|---|---|
| Cyan | The main live value: the number answering the page’s question |
| Pale cyan | A secondary live value |
| Green | Descending, arriving or healthy |
| Amber | Climbing, departing, holding, inferred information or something worth attention |
| Red | Emergency, go-around, severe descent, or the fixed north marker |
| Violet | Ground traffic or a circling behavior |
| Lilac | Space/ISS information or a survey pattern |
| Orange | Military flag supplied by the aircraft feed |
| Grid green | Non-data furniture: rings, ticks, runway outlines and scale |
| Grey | Labels, units and explanatory text |

Aircraft altitude coloring is a separate continuous gradient described earlier. When that option is enabled, the aircraft body uses altitude color while behavior rings, labels and page statistics retain the semantic colors above.

### Shapes and marks

| Mark | Exact meaning |
|---|---|
| Pointed chevron | Airborne aircraft; the point follows the reported true track |
| Fading track behind a chevron | Retained recent position fixes—where the aircraft actually went |
| Thin line ahead | Velocity leader—where present heading and groundspeed would carry it |
| Violet dot | Stationary or nearly stationary ground contact |
| Violet dot with stub | Moving ground contact/taxiing |
| Faint mark pinned to the rim | Known contact outside the drawn scope but inside the fetched picture |
| Colored ring around aircraft | Detected holding, circling, survey, go-around or emergency descent |
| Red triangle at top | True north |
| Dim rotating radial line | Decorative radar sweep; it does not trigger detections |
| Bright traveling rim arc | Health ring and proof that the display loop is alive |

### Health colors

| Health color | Meaning |
|---|---|
| Violet | Boot has begun |
| Blue | Connecting or actively fetching |
| Amber | Warning, retry, stale information or degraded feed |
| Cyan | Network/data initialization progressing |
| Green | Normal operation and fresh data |
| Pulsing red | Emergency aircraft alert |

---

## Every on-screen term

### RADAR terms

| Term or number | Meaning |
|---|---|
| Number at top | Airborne aircraft inside the currently drawn radar range |
| Number at left | Aircraft climbing inside that same drawn range |
| Number at right | Aircraft descending inside that same drawn range |
| Outer “km” label | Current radar edge; AUTO changes this value only |
| Three rings | ¼, ½ and ¾ of the outer radar range |
| AUTO | Automatic range selection is enabled |
| Callsign tag | Radio callsign, not necessarily the passenger-facing flight number |
| HOLD / CIRC / SURV / G/A | Holding, circling, survey pattern or go-around |
| Clock | Local time in the selected 12- or 24-hour format |
| Site label | The short home/airport identity chosen for this build |

### AIRPORT terms

| Term or mark | Meaning |
|---|---|
| MUC / EDDM | Munich Airport’s presentation label and ICAO weather station |
| Runway numbers | Magnetic runway direction rounded to the nearest ten degrees |
| ARR | Descending/approaching aircraft associated with the field |
| DEP | Climbing/departing aircraft associated with the field |
| Active runway highlight | Runway end most nearly facing the reported METAR wind |
| Amber inferred direction | Wind was unusable, so nearby descending traffic supplied the estimate |
| Ground chevron | Moving on a runway |
| Ground stub | Taxiing |
| Ground dot | Parked or nearly stationary |
| MILITARY / HEAVY / ROTARY | Most notable nearby airport contact category |

The airport callout gives priority to operationally interesting traffic: emergency squawk +120, go-around +70, military +60, heavy category +45, high-performance category +30 and rotorcraft +25. A score of at least 40 earns the box, and the strongest candidate is shown. Its reason label follows strict priority: EMERGENCY, GO-AROUND, MILITARY, ROTARY, HEAVY, then HIGH PERF.

### TRAFFIC terms

| Term | Meaning |
|---|---|
| AIRBORNE WITHIN … KM | Live airborne count inside the fixed activity radius |
| CLIMBING | Positive vertical-rate contacts |
| DESCENDING | Negative vertical-rate contacts |
| OVER FL300 | Aircraft above flight level 300 / 30,000 ft |
| ON GROUND | Contacts reporting ground state |
| ROTARY | Helicopters/rotorcraft identified from aircraft category |
| MILITARY | Contacts explicitly flagged military by the feed |
| MOSTLY N/NE/E/SE/S/SW/W/NW | Busiest of eight bearing sectors around home |
| One-hour line | 60 one-minute mean traffic samples |
| collecting… | Not enough complete clock minutes yet |
| no clock yet | NTP time is not available, so minute buckets cannot be committed |

### NEAREST and COOLEST terms

| Term | Meaning |
|---|---|
| Large callsign | Selected aircraft identity |
| Airline/operator | Enriched operator when the lookup source knows it |
| Type | Aircraft model/type description |
| Registration | Civil registration/tail number |
| Route | Known origin and destination from enrichment |
| Distance | Current great-circle/local-plane distance from home |
| Bearing/cardinal direction | True bearing and its readable compass sector |
| ALT | Barometric altitude in feet |
| GS | Groundspeed in knots |
| VS | Vertical speed in feet per minute |
| CPA | Predicted closest point of approach if course and speed remain constant |
| T− / minutes | Time until that predicted CPA |
| MIL | Military flag from the live feed |
| COOLEST reason | Strongest reason the contact won: behavior, military, rotorcraft, rarity or heavy type |

### SPACE terms

| Term | Meaning |
|---|---|
| AZ | True azimuth from home to the ISS |
| EL | Elevation above the observer’s horizon |
| DIST | Great-circle ground distance |
| Horizon ring | 0° elevation |
| Center of dome | Zenith / 90° elevation |
| VISIBLE | Above 10°, station sunlit and home dark |
| NEXT PASS | First predicted crossing above 10° in the next 24 hours |
| MAX EL | Highest estimated elevation during that pass |
| T− | Time remaining until a scheduled launch |
| T+ | Time elapsed since its scheduled launch time |
| NO PASS 24H | No qualifying pass found within the search window |

### WEATHER terms

| Term | Meaning |
|---|---|
| METAR | Standard coded airport weather observation |
| Age | Time since the observation itself, not time since the device downloaded it |
| VFR | Visual conditions |
| MVFR | Marginal visual conditions |
| IFR | Instrument conditions |
| LIFR | Low instrument conditions |
| WIND | Direction wind comes from and speed in knots |
| VIS | Reported visibility |
| TEMP / DEW | Air temperature and dew point |
| Near-dew warning | Temperature and dew point separated by roughly 2°C or less |
| QNH | Sea-level pressure in hectopascals |
| Clouds | Reported cloud amount/base decoded from the METAR |
| NO METAR | No usable report is currently available for EDDM |

### PATTERNS terms

| Term | Meaning |
|---|---|
| HOLDING | Repeated coordinated turn/racetrack-like containment |
| CIRCLING | Tight, slower orbit in a small area |
| SURVEY PATTERN | Multiple reversals and long path with little net displacement |
| GO-AROUND | Descent to a real low point followed by a sustained climb |
| EMERGENCY DESCENT | Extreme descent rate plus significant altitude loss |
| FAST CLIMB | More than 2,500 ft/min below 20,000 ft |
| APPROACH | Descending, below 15,000 ft and getting closer inside 45 km |
| DEPARTURE | Climbing, below 15,000 ft and getting farther inside 45 km |
| OVERFLIGHT | Above 24,000 ft and approximately level |
| LEVEL | No stronger behavior classification applies |

### TRENDS terms

| Term | Meaning |
|---|---|
| LEARNING | Not enough valid observations exist for the applicable baseline yet |
| Normal | z-score from −1 to +1 |
| Busier / Quieter | z-score beyond ±1 |
| Much busier / Much quieter | z-score beyond ±2 |
| Baseline | Learned mean for the hour, refined by weekday/hour as history matures |
| History line | Last 24 observed hourly values |
| Progress | Coverage of the weekly model, not a network-download percentage |

### SYSTEM terms

| Term | Meaning |
|---|---|
| FETCH OK | Percentage of aircraft polls that returned a usable payload |
| FEED | adsb.lol primary or adsb.fi fallback |
| Data age | Elapsed time since the last good aircraft picture |
| Wi-Fi / RSSI | Network name and received signal strength |
| Frame time / FPS | Display-rendering performance |
| RAM | Internal memory available to the time-critical renderer/network stack |
| PSRAM | External memory used for larger histories and supporting data |
| Uptime | Time since boot |
| Status/last result | Current network task state and most recent request outcome |

### ABOUT

ABOUT contains the owner credit, product revision and animation. It does not affect aircraft processing. The Munich configuration has eleven pages when ABOUT is enabled; the default cycle excludes ABOUT and has ten. Disabled pages are skipped by MODE and automatic cycling.

---

## Everything configurable

The captive setup page exposes the controls that genuinely affect the current hardware. Settings that could not work on this seven-pin display—backlight brightness, night dimming, runtime SPI speed and RGB-order changes—were deliberately removed.

### Setup portal, shown from the firmware page

These captures use the current portal HTML and synthetic settings. The Wi-Fi names and coordinates are examples; no device credentials appear here.

| Wi-Fi | Home location |
|---|---|
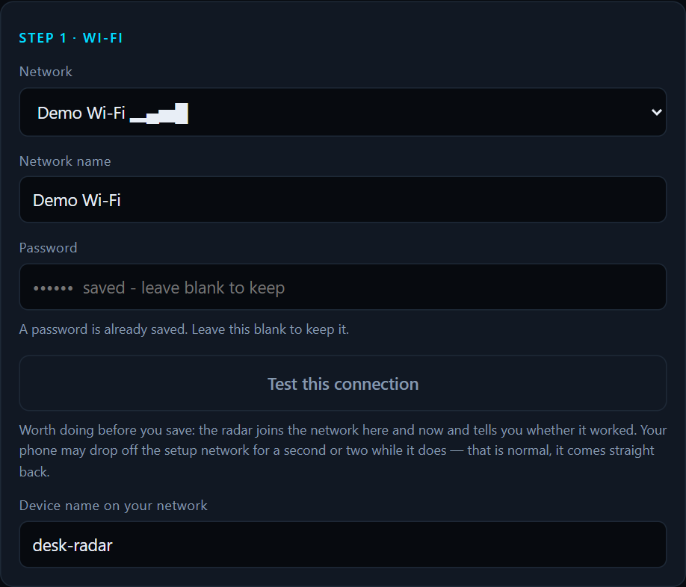
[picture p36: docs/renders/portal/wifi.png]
Desk Radar setup portal Wi-Fi step with a demo network
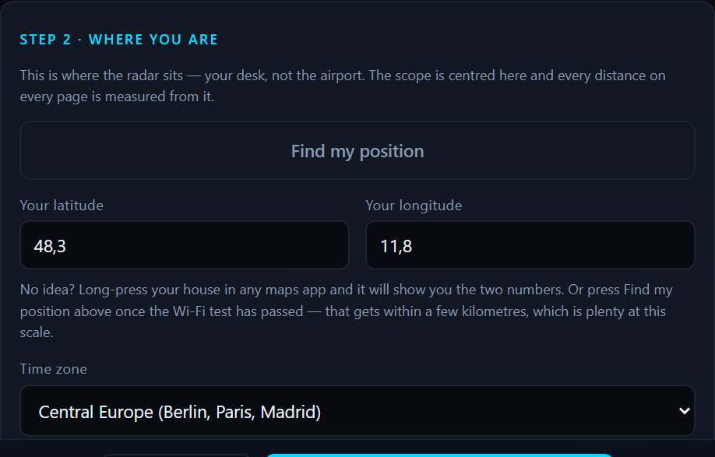
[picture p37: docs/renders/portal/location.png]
Desk Radar setup portal home-location step
|  |  |
| Radar scope | Page selection |
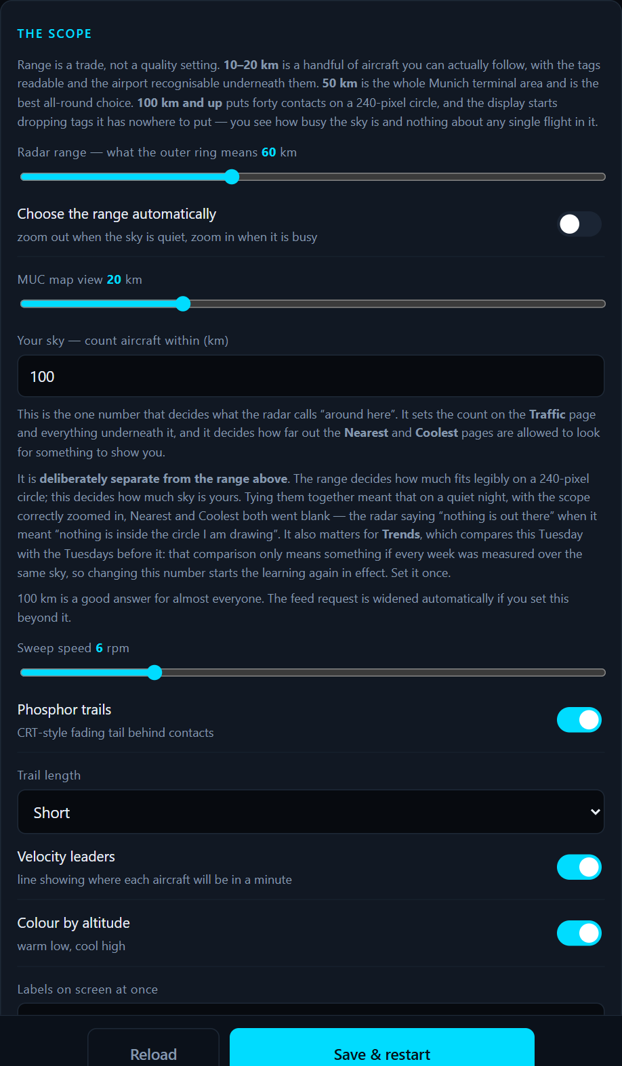
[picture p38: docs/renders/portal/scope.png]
Desk Radar setup portal radar range and scope controls
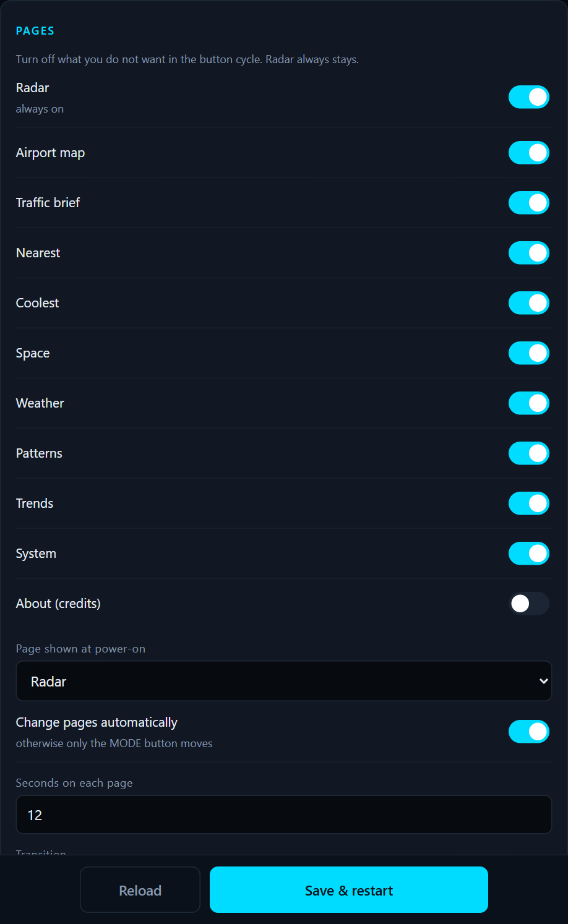
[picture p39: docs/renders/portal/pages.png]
Desk Radar setup portal page selection and transitions
|  |  |

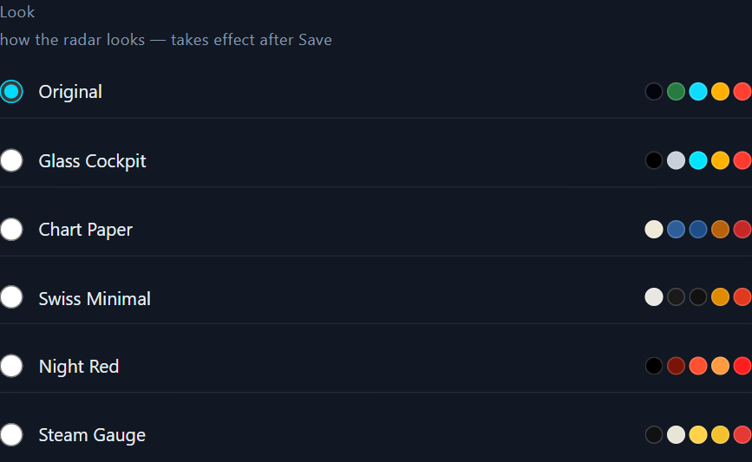
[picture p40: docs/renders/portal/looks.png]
Desk Radar setup portal Look picker with Original and five new choices


| Setup area | What can be changed | Effect |
|---|---|---|
| Wi-Fi | Scanned/manual 2.4 GHz network, password, connection test, hostname | Moves the radar to a network without reflashing |
| Home | Latitude, longitude and time zone | Center for radar, distance, bearing, traffic, Trends and solar calculations |
| Radar range | Fixed 10–150 km slider | Outer ring when AUTO is off |
| AUTO | On/off, minimum and maximum range | Lets traffic density choose a rung inside the allowed window |
| Airport map | 5–60 km | Scale of the Munich Airport page |
| Your sky | 5–400 km activity radius | Fixed meaning of local traffic for Traffic, Coolest, Patterns and Trends |
| Sweep | 2–20 rpm | Visual sweep speed only |
| Phosphor | On/off and long/medium/short/very-short decay | Persistence of the CRT-style drawing layer |
| Velocity leaders | On/off | Future-position direction/speed cue |
| Altitude color | On/off | Warm-low to cool-high aircraft symbols |
| Labels | 0, 1, 2, 3, 5 or 8 | Maximum simultaneous callsign tags |
| Pages | Enable/disable, starting page | RADAR always remains enabled |
| Auto-cycle | On/off and 4–120 second dwell | Automatic page advance |
| Transition | Instant, fade, slide or iris | Animation between pages |
| Screen | Original or five new looks; 0°, 90°, 180° or 270° rotation; color inversion | Visual style and physical orientation/panel correction; Look applies after Save and restart |
| Status LED | Enabled, alerts-only, brightness and supported board pin | Mirrors the health ring or stays dark until needed |
| Aircraft refresh | 6–300 seconds | Live feed polling; 8 seconds is the recommended balance |
| Fetch radius | 20–250 km | Base area requested before automatic widening |
| Enrichment | On/off | Aircraft type, registration, operator and route lookups |
| Space data | On/off | ISS and launch requests/page data |
| Emergency alerts | On/off | Full-screen 7500/7600/7700 interruption |
| Military-only | On/off | Hides civil contacts from the view; AUTO still measures the full sky |
| Learned baseline | Restart learning | Clears Trends history without erasing Wi-Fi |
| Personal | Owner name and 12/24-hour clock | ABOUT credit and radar clock |
| Maintenance | Erase all settings | Returns the device to first-run Wi-Fi setup |

This build is fixed to **Munich (MUC / EDDM) only**. No other airport can be selected. Its runway geometry comes from the firmware’s airport data. Home coordinates remain independently configurable.

### Button and automatic navigation

| Action | Result |
|---|---|
| Short MODE press | Advance to the next enabled page |
| Hold MODE for about 1.2–2 seconds | Restart into the setup portal |
| Quick double RESET | Alternate route into setup |
| Auto-cycle enabled | Advance after the selected dwell time |
| Emergency active | Freeze normal navigation on the warning |

Do not hold BOOT/MODE while applying power. GPIO0 is also the programming strap; holding it during reset asks the ESP32-S3 to wait for flashing, leaving the display black until a normal restart.

### Units

Choose **Aviation** (default) or **Metric** in setup.

| Measurement | Aviation | Metric |
| --- | --- | --- |
| Air distance | NM | km |
| Airport map scale | km | km |
| Altitude | ft | m |
| Ground speed | kt | km/h |
| Climb / descent | fpm | m/s |
| Wind | KT | MPS |
| Visibility | SM | km |
| Temperature / pressure | °C / hPa | °C / hPa |

The airport map keeps kilometres for runway geometry. Visibility uses statute miles in
aviation mode. Flight levels appear in aviation mode; metric mode shows height instead.
Some fixed diagnostic and emergency labels retain the units printed beside their values.
Range controls are configured in kilometres even when the scope displays nautical miles.

---

## Connection and recovery messages

| Message | Meaning | Normal action |
|---|---|---|
| joining | Connecting to the saved router | Wait |
| connected | Network association succeeded | None |
| network not found | SSID absent, mistyped or unavailable | Reopen setup and select it |
| wrong password? | Router rejected authentication | Re-enter the password |
| no answer from AP | Network is visible but did not answer | Improve Wi-Fi range |
| connection lost | A previously working link dropped | Device reconnects itself |
| reconnecting | Automatic recovery is running | Wait |
| join timed out | Router did not finish association | Wait or reopen setup |
| no credentials | No Wi-Fi has been saved | Join DESK-RADAR-xxxx |
| net task up | Networking task started | None |
| reading baseline | Loading learned traffic history | None |
| allocating buffers | Reserving network/parser memory | None |
| out of memory | Required working memory could not be reserved | Reflash/check build configuration |
| PSRAM off in build | External RAM support was disabled when flashed | Reflash with PSRAM enabled |
| collecting… | Waiting for enough time-based samples | Wait |
| NO METAR | Weather report unavailable | Check later/verify airport source |
| LEARNING | Trends needs more valid hourly history | Let it run with a fresh feed |

One missed aircraft poll is treated as noise. The device keeps the last valid picture, reports age honestly and warns only after repeated misses make the feed stale.

---

## Aviation glossary

| Term | Plain-language meaning |
|---|---|
| ADS-B | Automatic Dependent Surveillance–Broadcast: aircraft transmitting identity, position and motion |
| Callsign | Radio identity used by air traffic control; related to but not always equal to the ticketed flight number |
| Squawk | Four-digit transponder code |
| Knot | One nautical mile per hour, approximately 1.852 km/h |
| Flight level | Pressure altitude in hundreds of feet; FL300 means 30,000 ft |
| METAR | Standard airport weather observation |
| QNH | Pressure reduced to sea level for altimeter setting |
| VFR / IFR | Visual / instrument flight rules and their associated weather categories |
| CPA | Closest point of approach under constant-course, constant-speed projection |
| Go-around | A landing approach discontinued into a climb |
| Hold | Repeating racetrack-like path while waiting or sequencing |
| Heavy | Wake-turbulence category for large aircraft such as the 747, 777 or A380 |
| Rotorcraft | Helicopter or other rotary-wing aircraft |
| True bearing | Direction relative to geographic north |
| Magnetic runway number | Runway heading relative to magnetic north, rounded to tens of degrees |
| NTP | Internet time synchronization used for clock, minute/hour buckets and solar calculations |

---

## Hardware and wiring

The physical build is intentionally small: two main electronic parts and one button.

- ESP32-S3-WROOM-1 N16R8;
- GC9A01 1.28-inch round IPS display;
- onboard BOOT button as MODE;
- USB-C power.

### 3D enclosure

The [sleek radar enclosure files](enclosure/sleek-radar/) include an A1 mini PLA **3MF print plate** for the body and LED lid, a separate display-cap **STL**, and an editable **STEP** model. The final CAD renders show the front and rear:

| Front CAD render | Rear CAD render |
|---|---|
| Front CAD render of the sleek 3D enclosure | Rear CAD render of the sleek 3D enclosure |

The [CAD verification record](enclosure/sleek-radar/Final_verification.json) reports watertight print meshes and clearance checks. **Physical fit, LED light transmission and slicer preview have not been verified**; check those before committing to a full print. The STEP and meshes are provided for inspection and adjustment, especially if your ESP32-S3 or display module has different mechanical dimensions. The BOOT/MODE button sits on GPIO0, so the housing must not press it during power-up.

### Real device photos — waiting for owner images

| Finished device on a desk | Screen operating in use | Rear, side and cable view |
|---|---|---|
| *Saurav's photo to be added* | *Saurav's photo to be added* | *Saurav's photo to be added* |

This row is intentionally text until real photographs are supplied. CAD renders and synthetic firmware captures above should not be mistaken for photographs.

### Seven display connections

| ESP32-S3 | Display | Purpose |
|---|---|---|
| GPIO12 | SCL | SPI clock |
| GPIO11 | SDA | SPI data |
| GPIO13 | DC | Data/command |
| GPIO10 | CS | Chip select |
| GPIO14 | RST | Reset |
| 3V3 | VCC | **3.3 V only—never 5 V** |
| GND | GND | Ground |

This seven-pin module has no BLK pin; its backlight is always on. MODE uses the board’s onboard BOOT button on GPIO0.

Keep the high-speed SPI wires under roughly 10 cm. Longer leads can produce sparkles and torn rows that look deceptively like a graphics bug.

### Why the rendering architecture matters

The complete 240 × 240 frame is composed off-screen, then sent to the GC9A01 as one image. This prevents visible partial redraws.

The framebuffer remains in internal SRAM so DMA can transfer it reliably. PSRAM is useful for larger history and lookup structures, but a display sprite allocated there can silently lose the fast DMA path.

Antialiased drawing targets the off-screen sprite, never the physical panel. The GC9A01 cannot be read back reliably for alpha blending, so attempting to smooth directly onto the display produces incorrect edges.

The network and display work are separated so a slow web request does not freeze a sweep. This is what allows a roughly 40 fps instrument to coexist with several slower internet feeds.

---

## Data sources and cadence

All sources are public and require no account for this personal project.

| Data | Primary source | Typical refresh | Use |
|---|---|---:|---|
| Live aircraft | [adsb.lol](https://adsb.lol/) | ~8 s | Positions, tracks, altitude, speed, squawk |
| Aircraft fallback | [adsb.fi](https://adsb.fi/) | On primary trouble | Continuity when the preferred feed fails |
| Aircraft enrichment | [adsbdb](https://www.adsbdb.com/) | On demand | Type, registration, airline and route |
| Airport weather | [Aviation Weather Center](https://aviationweather.gov/) | ~10 min | METAR, wind, visibility, flight category |
| ISS | [Where the ISS at?](https://wheretheiss.at/) | ~60 s | Live orbital position and velocity |
| Launches | [The Space Devs](https://thespacedevs.com/) | ~30 min | Next four launch events |

Volunteer ADS-B services can be incomplete or temporarily unavailable. The radar reports source age and fetch health rather than pretending that stale data is live.

---

## Using it

On first power-up, the radar creates an open Wi-Fi network named **DESK-RADAR-xxxx**. Scan the display’s Wi-Fi QR code or join that network manually. Open **http://192.168.4.1/**, choose the home 2.4 GHz network, enter its password and save. Setup settings survive restarts. The portal is a setup mode, not an always-on web dashboard. A quick double RESET within the eight-second startup window also opens setup.

After that:

- press MODE to move through enabled pages;
- hold MODE for about 1.2 seconds after startup to reopen settings;
- choose which pages participate in the cycle;
- set radar, AUTO, activity and airport-map ranges;
- control refresh timing, alerts, clock, status light and personalization;
- erase all settings before transferring the device to somebody else.

The startup status light walks **violet → blue → amber → cyan → green**, giving a clue about where startup stopped even if the main display is blank.

The display module has no controllable backlight pin, so brightness and automatic night dimming are intentionally absent.

---

## Reliability and final status

The revision 2.0 baseline includes a corrected weather text-formatting bug, one-time font initialization
with fallback, memory checks before optional network requests, bounded recovery attempts,
validation of orbital data and protection against learning from stale observations.
Optional information can wait when memory is tight; the main aircraft feed has priority.
These fixes do not establish a guarantee of indefinite uptime.

The setup page’s Health section explains the current condition and links to the diagnostic log.
With the FATFS partition used by the verified Arduino build, logs roll between two 1 MB
segments. Opening setup restarts the device, so the persisted log is useful for investigating
the previous run. A missing log filesystem falls back to Serial logging.

**Revision 2.1 audit:** removes the other airports, handles startup allocation failures,
validates saved settings, bounds slow HTTP replies, repairs timer and stale-data behavior,
and makes Wi-Fi scan/test controls responsive through polling. Network names are rendered
as text and failed saves no longer claim success. Corrupt learning data is rejected. Slow diagnostic-log clients cannot hold the network task
indefinitely or leave the renderer waiting for the file-log lock.
The [audit report](docs/AUDIT_REV2_1.md)
records executed checks and the remaining physical verification.

**Still a physical check:** no hardware was flashed during this publication. A long-running
test with real Wi-Fi/TLS traffic and page transitions is still needed to confirm stability.
The project is closed out as a source and documentation snapshot, not a claim of completed
hardware endurance testing. ADS-B coverage and derived behaviour can be incomplete; use this
as a personal spotting display, never for navigation or operational decisions.

## Project files and rights

This README is the complete public guide for the Munich desk radar. Screen images and
enclosure concepts remain in the repository as visual references. The printable enclosure
exports are in [enclosure/sleek-radar](enclosure/sleek-radar/). Photos of the real assembled
device in use will be added when the owner supplies them. Standalone manuals have
been retired so that explanations are maintained here.

Firmware, regression checks and build instructions live in
[desk_radar_esp32_code](https://github.com/haldarsaurav/desk_radar_esp32_code).
Repository access depends on its permissions. This public showcase contains no firmware,
private configuration or device credentials.

Copyright 2026 Saurav Haldar (haldarsaurav). All rights reserved. Read [LICENSE](LICENSE) and the
[permission guide](docs/PERMISSIONS.md) before reusing project material. Libraries, fonts,
data and other third-party material keep their own terms. This is an independent personal
project, with no affiliation with Munich Airport, airlines or feed providers.

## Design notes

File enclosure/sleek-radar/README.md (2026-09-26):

# Sleek Radar 3D enclosure

This directory contains the final **CAD export** for the compact desk enclosure, sized for the project's ESP32-S3 N16R8 board and 1.28-inch GC9A01 display. The shape is shown in [front](Final_front.png) and [rear](Final_back.png) renders.

| File | Use |
| --- | --- |
| [A1 mini PLA plate](PRINT_THIS_BODY_AND_LED_LID_A1mini_PLA.3mf) | Prepared body and LED-lid print arrangement; the display cap is separate |
| [Body STL](01_POLISHED_BODY.stl) | Individual main-body mesh |
| [LED lid STL](LED_LID_PRINT_THIS.stl) | Individual lid mesh |
| [Display cap STL](CAP_ASSEMBLED.stl) | Separate display-cap mesh, absent from the 3MF plate |
| [STEP assembly](Sleek_Radar_Final.step) | Editable CAD geometry for adaptation and fit inspection |
| [Verification record](Final_verification.json) | Export, clearance and mesh checks |

The record reports valid single solids, watertight meshes and checked clearances for the body and LED lid. Its `physical_fit_and_LED_transmission_tested` and `slicer_preview_verified` fields are **false**. Treat the 3MF as a prepared starting plate and add the display cap STL separately; inspect all parts in your slicer, confirm orientation and settings, then test the display, buttons, USB plug and LED transmission against your specific parts. The nominal outer dimensions are **50 × 98 × 63.8 mm**.

The board's BOOT/MODE button is on GPIO0. Check that the printed button does not stay pressed when the power cable is inserted or the board resets.

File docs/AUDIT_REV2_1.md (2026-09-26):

# Revision 2.1 logic audit

**26 September 2026 · Project: Saurav Haldar · Baseline: revision 2.0 (`9535025`)**

The baseline was formerly labelled product 2.3 / firmware 5.7.1. This release resets
current labels to 2.1 and preserves the historical comments and Git history.

## Scope and results

The audit traced startup, settings, the two tasks and shared state, each page's dispatch,
network scheduling and parsers, recovery, learning, geometry and setup UI. Both site builds
receive the same implementation. Munich has only MUC/EDDM; Estonia has only Tallinn/EETN
and Tartu/EETU. Old picker selections cannot recreate removed pages or network requests.

This is a source audit with targeted executable regressions, not exhaustive proof of every
input or interleaving. Hardware endurance, radio behavior and low-memory failure injection
on the ESP32 remain physical checks. Host transport tests simulate HTTPClient; they do not
exercise mbedTLS or the radio driver.

## Changes by file (relative to each sketch)

| Files | Finding and revision 2.1 behavior |
| --- | --- |
| `config.example.h`, local `config.h`, `src/airports.cpp`, `src/airports.h` | Munich's picker is disabled and its four other table entries removed. Estonia remains fixed Tallinn + Tartu. Credentials stay local. |
| `src/settings.cpp` | Defaults now pass the same validation as saved settings. Fixed airport identities override old NVS/API input; obsolete extra masks are cleared. Tartu takes the validated current map range. Saved timezones survive loading. Unknown page bits, absent/disabled start pages, unsupported unit/clock modes, unterminated names and arbitrary LED pins are sanitized. The read-only load path no longer tries to delete an NVS key. Settings schema stays 2, preserving credentials and learning. |
| `*.ino` | Check mutex creation before use; create/check the render task before launching networking, entering setup on those failures. The startup status read takes the state mutex. Disabled or stale emergency alerts no longer prevent button/automatic page changes. Revision history is recorded in the sketch header. |
| `src/net.cpp` | HTTP body reads have both idle and total-duration limits. Each aircraft attempt resets its failure classification. Fallback deadlines compare safely across timer wrap, and retry backoff starts after request completion. Offline status/LED and feed age update immediately. The renderer ages feed snapshots during blocked network work, so stale alerts expire. Auto-range samples are discarded across outages. Query longitude uses a wrapped midpoint without dividing by a polar longitude scale. |
| `src/portal.cpp` | Wi-Fi scan and join run through polling rather than an 18-second blocking HTTP handler. Scan JSON escapes arbitrary SSID characters. Geolocation uses bounded storage/read time and validates coordinates. A new SSID does not inherit another network's password. JSON save/test bodies must be objects. |
| `src/portal_page.h` | Requests have deadlines; pending scan and Wi-Fi results are polled. A failed retest clears prior location/results. SSIDs and location text cannot inject HTML. Unconfirmed saves no longer claim success. |
| `src/model.h`, `src/pages.cpp`, `src/page_data.cpp` | Emergency indices must refer to a retained contact; stale data cannot draw a live emergency overlay. Detail-page selections are checked before indexing. |
| `src/dbglog.cpp`, `src/dbglog.h`, `src/net.cpp` | Log body sends use nonblocking sockets with a shared 10-second limit, including partial sends; request draining is bounded. File-log lock acquisition is limited to 20 ms so concurrent render logs fall back to Serial. A failed log mutex allocation disables FATFS logging. |
| `src/geo.h` | Date-line offsets take the short displacement; antipodal haversine rounding cannot take a negative square root. |
| `src/baseline.cpp` | Nonfinite samples are ignored. NVS blobs are checked for exact size, magic, finite values and bounded counters before replacing the live model. Null serialization inputs fail safely. |
| `src/health.h` | Accumulated success/failure totals use 64-bit addition before percentage calculation. |
| `src/app_info.h` | Screen, setup, boot and HTTP labels share revision 2.1. The User-Agent no longer claims a fixed request rate while the interval is configurable. |
| `tools/*_check`, root `tools/run_checks.py` | Added production settings tests, tests of the actual extracted HTTP helper with simulated transport, corrupt baseline/geometry/alert bounds checks and fixed-site asynchronous browser regressions. |
| Root `.github/workflows/checks.yml` | Run host suites, variant parity, pin checks, browser regressions and both pinned ESP32-S3 builds on GitHub pushes/PRs using public example configurations. Physical tests remain separate. |
| Root docs and rights notices | Revision tables, credit to Saurav Haldar and measured 0.6 W running cost; public showcase remains Munich-focused. |

## Reviewed paths retained

- **Memory and rendering:** internal DMA sprite; PSRAM world snapshots and JSON; font fallback;
  45,056-byte net / 8,192-byte render stacks; snapshot bounds; page transition buffer fallback.
- **Aircraft:** missing coordinates; finite/range clamps; nearest-contact capacity; ground/air
  classification; callsign cleanup; enrichment lookup; emergency and interest selection.
- **Optional sources:** feature/page masks; METAR station routing; ISS fix validation and bounded
  prediction; launch parsing; stale remote-airport age; main-feed priority under low memory.
- **Network recovery:** joining and reconnecting; missing PSRAM; empty/malformed/truncated replies;
  HTTP 401/403/429; fallback and quiet periods; bounded bounce/restart counts; healthy rearming.
- **Learning and UI:** stale/time-discontinuous buckets; both unit modes; first boot, saved settings,
  schema mismatch, page masks, long/short button paths, portal flags, learning/factory resets.

## Executed verification

The final results are recorded here before publication. Logs and firmware artifacts remain in
ignored `build/rev21/` and `build/checks_munich/`, `build/checks_estonia/`.

- Host suites: 18 per variant, including actual production settings, HTTP-body and log-send code.
- Browser: fixed Munich and Tallinn/Tartu controls, legacy generic UI regression coverage,
  pending Wi-Fi success/failure, request abort, malicious SSID/location text, stale location reset and unconfirmed-save handling passed.
- Variant parity and both pin maps passed.
- Real page code: 840 crash-regression draws per compiled variant completed; full-page fixtures
  exercised holding, circling, go-around and survey detection. Both site fixtures and credit screens rendered and inspected.
- ESP32-S3 build: both variants compiled and linked on 26 September 2026 from clean copies
  using their public `config.example.h`, Arduino CLI 1.5.1, ESP32 core 3.3.11,
  LovyanGFX 1.2.28, ArduinoJson 7.4.3 and TGX 1.1.4. The README's FQBN and
  `-Werror=format` setting were used. Munich used 1,457,387 bytes of program storage
  (46% of its partition) and 60,124 bytes of static RAM (18%); Estonia used
  1,457,791 bytes (46%) and 60,124 bytes (18%). Both exited successfully.
- GitHub Actions: workflow added; a remote run is separate from the local evidence above.

## Physical closeout and known limits

No board was flashed, and no 24–48-hour hardware soak was performed. Verify page cycling and
SPACE → WEATHER, Wi-Fi loss/recovery, setup and saved settings on each device. Preserve the
complete panic/reset log if a restart recurs. A successful build cannot prove steady-state
heap stability or resolve power-supply/radio faults.

Diagnostic log bodies stop after 10 seconds, so slow clients can receive a partial log.
During downloads, contended log lines remain on Serial rather than flash.

The portal's optional IP-location lookup can still briefly occupy the portal loop after
joining. Its browser poll allows 30 seconds for this slower result; ordinary requests use
an 8-second deadline. The HTTP transport has library-level connect/handshake timeouts plus the
new body deadline; TLS retries can delay new data while the independent renderer stays active.
TLS currently uses `setInsecure()` for public feeds. Certificate validation was not added.

The rendering harness uses synthetic state and can exercise extra-field slots that the shipped
configurations cannot select. The generic airport-picker browser cases are legacy regression
fixtures, not airports available on either device. Fixed-site settings tests cover the actual
compiled configurations. Default visible page counts are 10 (Munich) and 12 (Estonia); enabling
ABOUT adds one. Shared arrays retain their existing capacity.

The alternative PlatformIO partition lacks an `ffat` label, so persistent logs fall back to
Serial there. Reproduce the documented Arduino core/partition for FATFS logs. The ISS predictor
is approximate and external feed availability/coverage is outside this firmware's control.

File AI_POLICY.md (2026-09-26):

# AI and automated-use policy

**Prior written permission from Saurav Haldar / @haldarsaurav is required.**
This is a proprietary project. Public visibility is not an invitation to reuse it.

Without that permission, do not use protected project material:

- to train, fine-tune, distil, evaluate or improve AI/ML models, or to create datasets;
- in prompts, contexts, embeddings, retrieval stores or agent inputs for reuse or replication;
- as inspiration, a template, reference or specification to copy or reconstruct the project's
  implementation, documented logic, original screen design or expressive feature arrangement;
- to produce a rewritten, translated or non-verbatim version derived from that material.

The policy applies to human users and organisations operating AI systems, as well as model
providers and automated tools. Credit or noncommercial intent does not replace permission.
The owner's explicit instruction to a collaborator or tool authorizes only the requested work.

[Ask the owner for permission](https://github.com/haldarsaurav/desk_radar_esp32/issues)
and wait for an explicit written grant describing the permitted use. Include which material,
version, intended output, tools/models and distribution you propose. If issues are unavailable,
use a contact method published on [the owner's profile](https://github.com/haldarsaurav).

The full [LICENSE](LICENSE), including its third-party, platform and applicable-law provisions,
controls. This policy reserves permission; it is not a crawler blocker or a guarantee of legal
protection for abstract ideas, algorithms or general features.

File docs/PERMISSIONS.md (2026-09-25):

# Permission and reuse

**All rights reserved. Ask first, and receive written permission before reuse.**

The owner wants the project to be viewable as a showcase, without granting others permission
to copy its work or use it as a reference for an AI-generated replacement. Both repositories
carry the same [full proprietary licence](../LICENSE) and [AI-use policy](../AI_POLICY.md).

## Examples

| Proposed action | Owner's permission policy |
| --- | --- |
| Read the public feature guide on GitHub | Viewing through the service is covered by the applicable platform terms |
| Flash the firmware onto your own ESP32 | Ask for written permission first |
| Copy screen artwork or documentation into another project | Ask first |
| Sell a device incorporating the project | Ask first; disclose commercial use |
| Give an AI the files or screenshots to recreate the implementation or presentation | Ask first, including when the output uses different source text |
| Train a model, create embeddings for reuse, or build a dataset from the project | Ask first |
| Star the project, cite its URL or request permission | None of these actions grants reuse permission |

Requests should identify the requester, material/version, intended use, commercial status,
AI involvement and planned distribution. Send the request through the
[public repository's issues](https://github.com/haldarsaurav/desk_radar_esp32/issues)
or a contact method published on [the owner's profile](https://github.com/haldarsaurav).
Silence is not consent. Only the owner can grant project permission.

## What a notice can and cannot do

A restrictive notice expresses the owner's terms; it does not physically prevent downloads
or guarantee that third parties obey. GitHub's public-repository terms include service-specific
viewing and forking rights. See [GitHub's licensing guidance](https://docs.github.com/en/repositories/managing-your-repositorys-settings-and-features/customizing-your-repository/licensing-a-repository).

Copyright does not create ownership of abstract ideas, methods or algorithms simply because
they are described in a project. The licence therefore distinguishes protected project material
from generic features and independently created work. See the
[U.S. Copyright Office's software guidance](https://www.copyright.gov/register/tx-programs.html).
Legal protection and exceptions depend on applicable law; the notice preserves those limits.

Text/data-mining reservations can have jurisdiction-specific requirements. For example,
[German Copyright Act section 44b](https://www.gesetze-im-internet.de/urhg/__44b.html) specifies
machine-readable reservation for online works. These repository notices do not claim that a
particular crawler must recognize them or that every technical/formal requirement is satisfied.
Third-party libraries, data and trademarks keep their own terms.

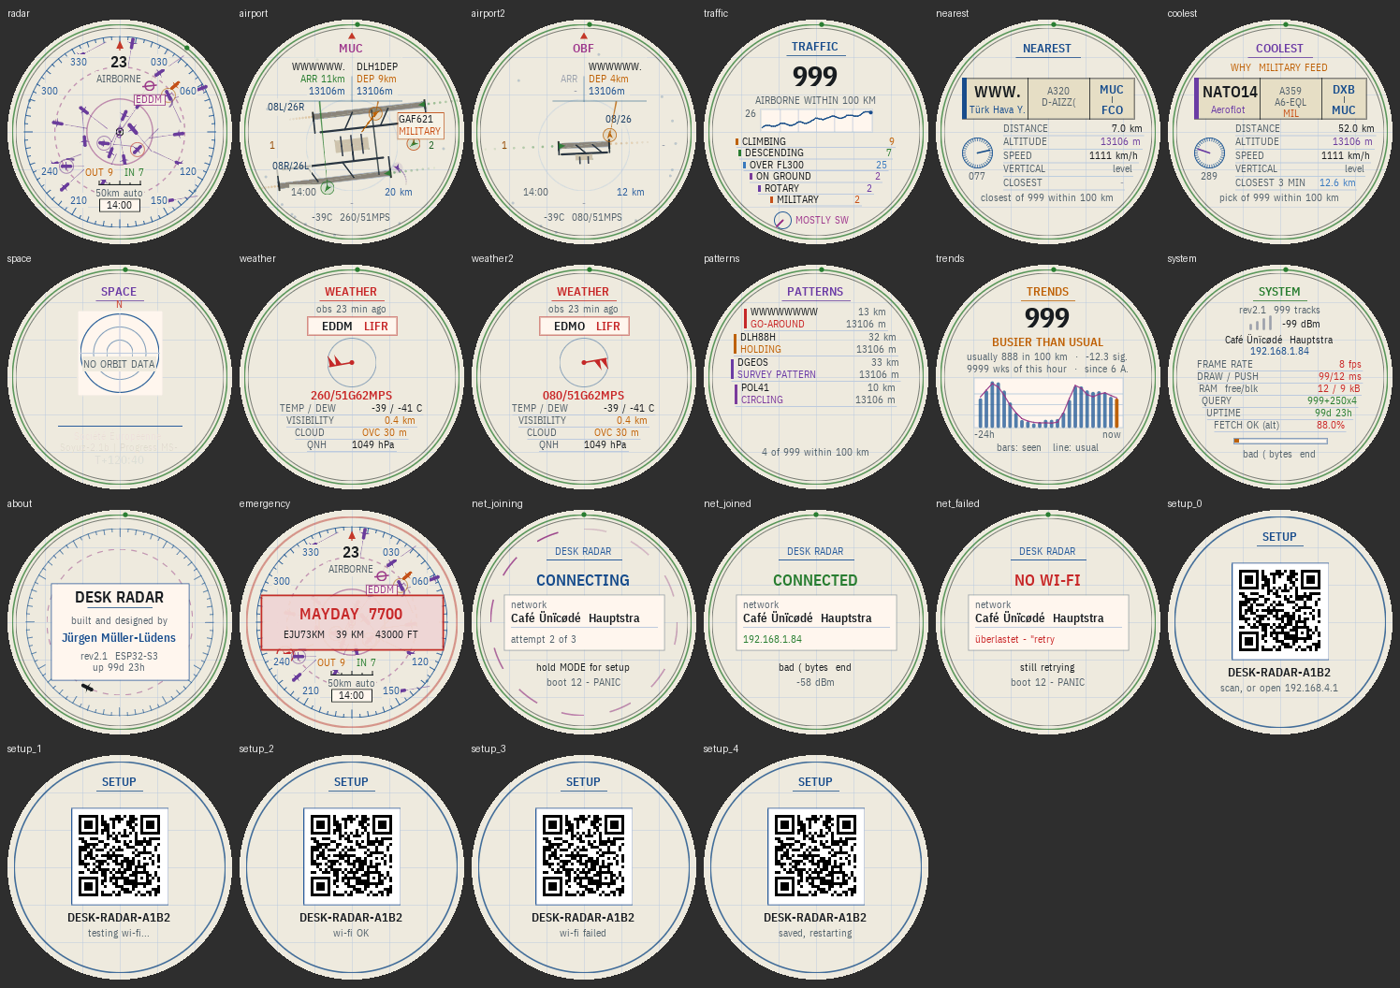
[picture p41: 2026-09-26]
docs/renders/looks/2_Chart_Paper_stress.png

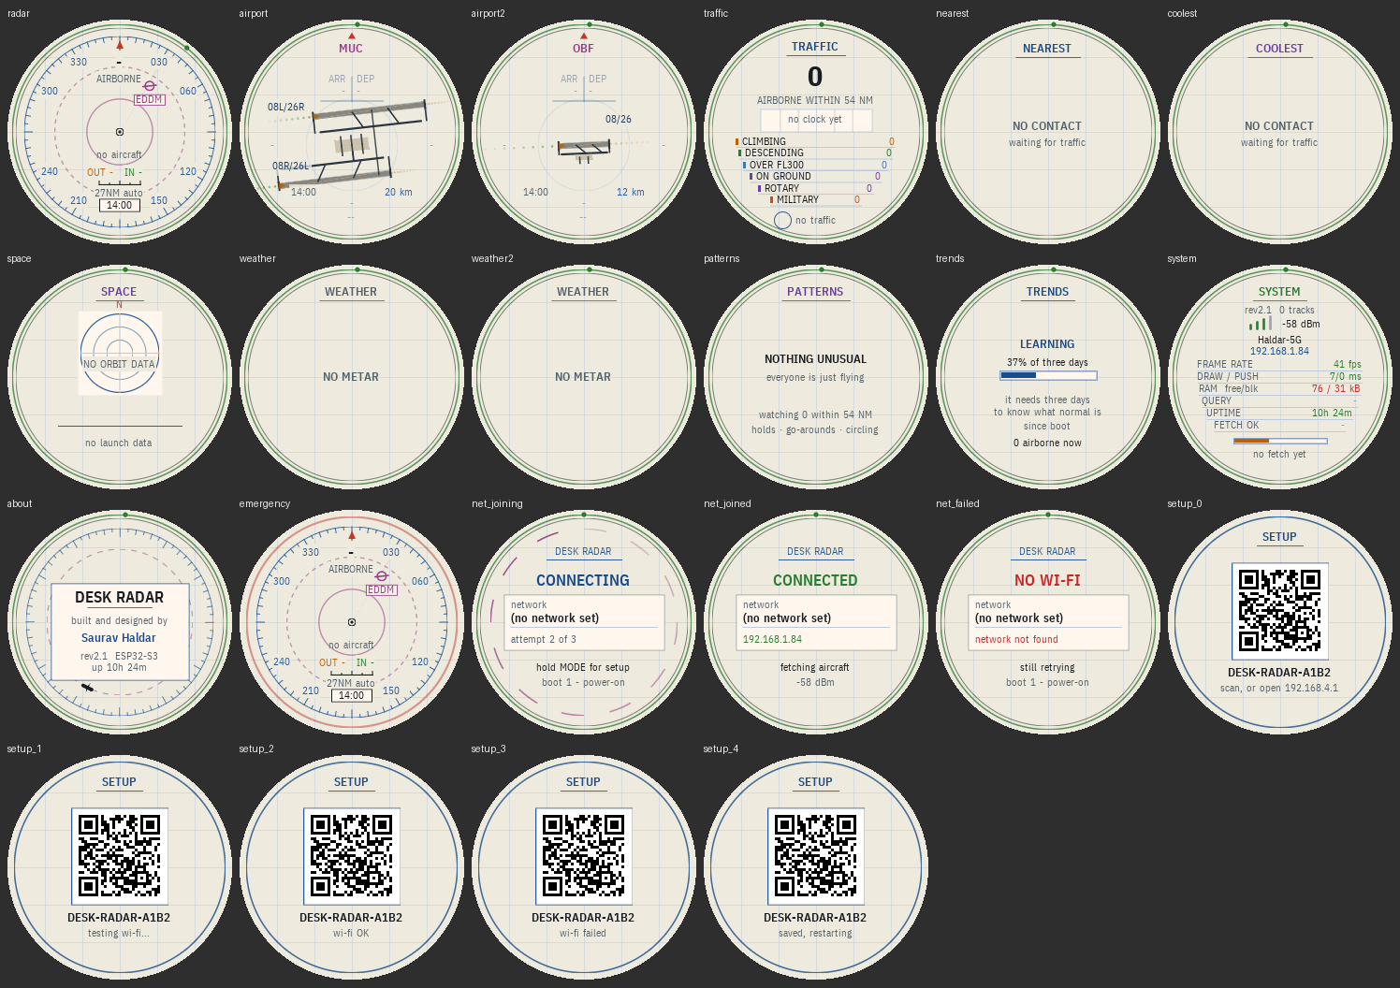
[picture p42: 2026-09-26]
docs/renders/looks/2_Chart_Paper_empty.png

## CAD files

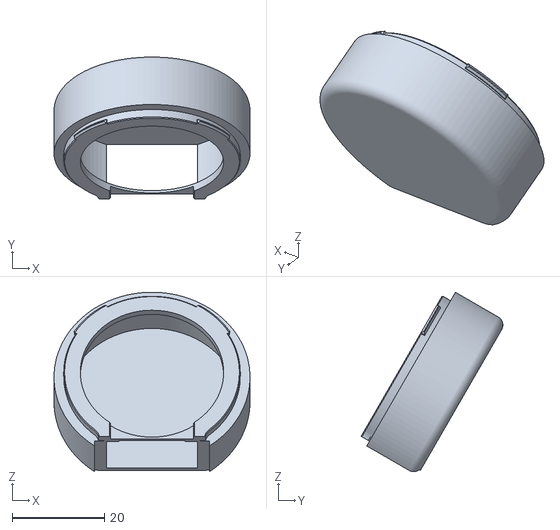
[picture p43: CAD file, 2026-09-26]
enclosure/sleek-radar/CAP_ASSEMBLED.stl
42.4 x 30.7 x 38.8

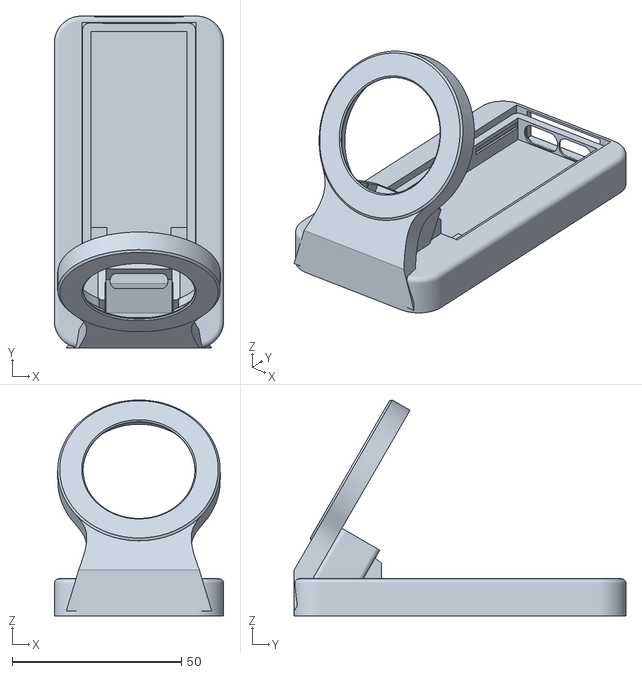
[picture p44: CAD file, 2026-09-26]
enclosure/sleek-radar/01_POLISHED_BODY.stl
50.0 x 98.0 x 63.8

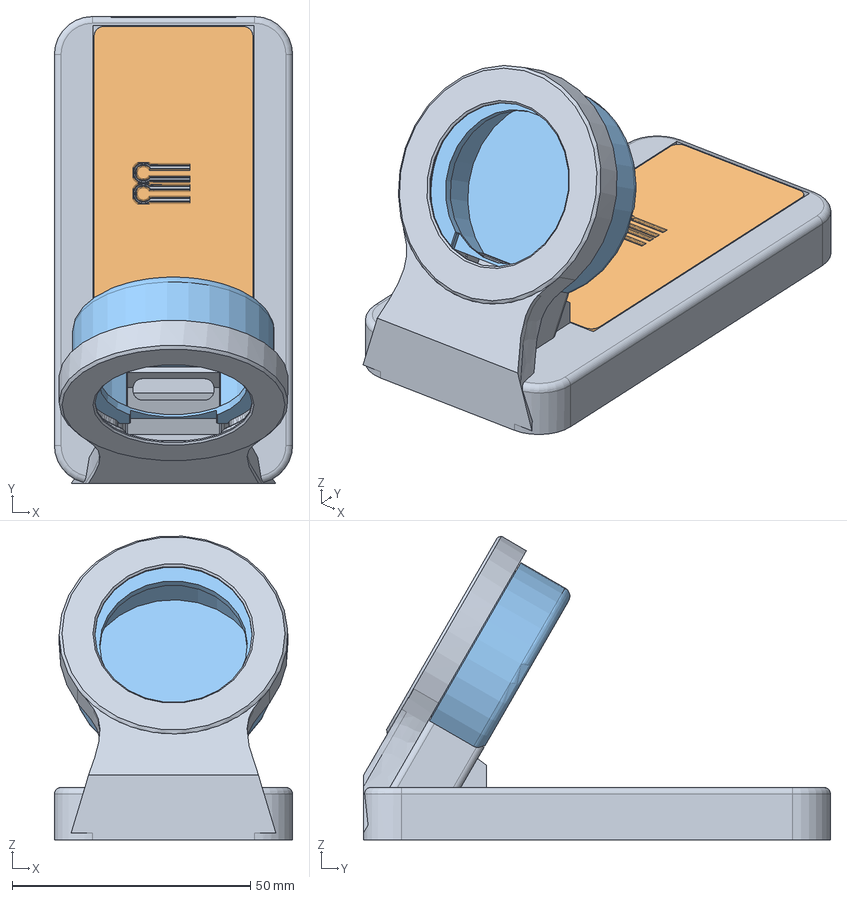
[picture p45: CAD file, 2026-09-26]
enclosure/sleek-radar/Sleek_Radar_Final.step
50.0 x 98.0 x 63.7 mm

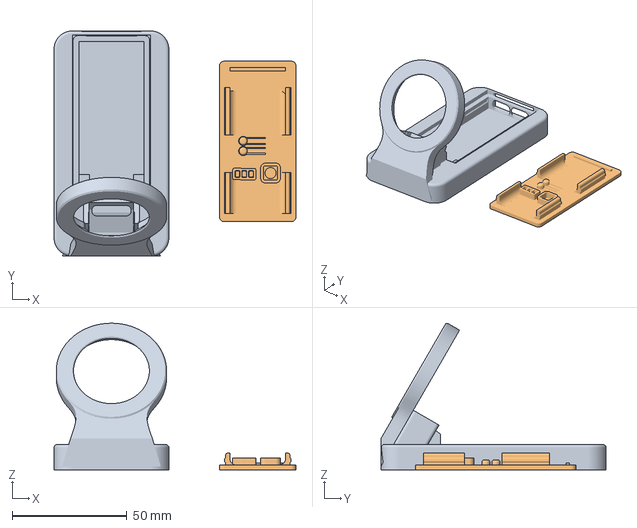
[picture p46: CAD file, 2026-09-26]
enclosure/sleek-radar/PRINT_THIS_BODY_AND_LED_LID_A1mini_PLA.3mf
105.3 x 98.0 x 63.8 mm
01_polished_body_larger_signature
02_LED_diffuser_lid_no_extra_button_nubs

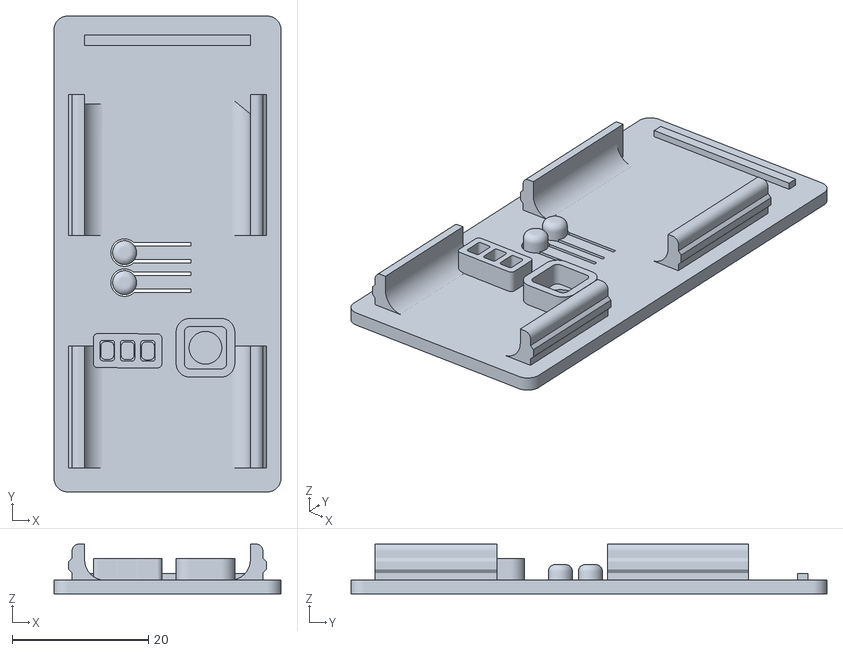
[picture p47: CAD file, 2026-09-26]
enclosure/sleek-radar/LED_LID_PRINT_THIS.stl
33.3 x 69.8 x 7.30

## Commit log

2026-07-01 Initial ESP32-C3 plane radar desk display project export
2026-07-01 Rename demo sketch to match Arduino sketch folder convention
2026-07-01 Add GC9A01 display test sketch and visual wiring guide - display verified working
2026-07-01 Visual overhaul: glass-cockpit theme, continuous sonar sweep, flight track page with CPA, bolder rim contacts
2026-07-01 Add MUC airport page (runways, arrivals/departures, ground traffic) and plane spotter page with coolness scoring
2026-07-04 plane_radar_v1.ino - rev1.0
    A standalone desk device that watches the sky around your home and Munich
    Airport (MUC/EDDM) on a 1.28" round display: live aircraft positions,
    airport arrivals/departures, a traffic brief, per-aircraft tracking cards,
    and decoded METAR weather. No app, no server — the ESP32 talks directly to
    free public APIs over Wi-Fi.
    [Plane_Radar.3mf]
2026-07-04 Trim repo to README only; keep code/docs local (build photos to be added later)
    [Plane_Radar.3mf]
2026-07-04 add README emoji polish and explicit radar ranges
    - Add emoji styling across README sections, page table, and feature lists
    - Document Home Radar 20/40/60 km range cycling
    - Add MUC distance behavior for 20 km map view and 20-40 km rim dots
    - Explain wider 60 km MUC flow and 100 km activity picture
    - Expand cool-aircraft distance logic for low overhead passes
2026-09-26 Document Rev 2.1 and publish visual and enclosure assets
    [01_POLISHED_BODY.stl, CAP_ASSEMBLED.stl, LED_LID_PRINT_THIS.stl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]
